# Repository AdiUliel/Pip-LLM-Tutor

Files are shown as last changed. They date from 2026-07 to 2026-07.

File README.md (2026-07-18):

# Pip — Personal Tutor for Kids | Project by: Adi Uliel, Lotan Dahan & Maor Amitay

## Details about the project

Pip is a robot that tutors children aged 7–11 in English or Math by voice
(powered by Google Gemini), with an animated face that keeps the child engaged.
A companion Flutter parent app is used for setup, homework materials and
progress reports.

Live web app: https://llm-tutor-d721e.web.app

**How to operate the device** (pairing, daily use, error messages, calibration):
see [Documentation/USAGE.md](Documentation/USAGE.md).

## Folder description :
* **ESP32**: source code for the esp side (firmware) — `homework_assistant/` is the main sketch, plus the modified TFT_eSPI library.
* **flutter_app**: Dart code for our Flutter parent app (Android / Web).
* **firebase**: Cloud side — Cloud Functions (session engine, Gemini grading, STT/TTS proxies), Firestore/Storage rules and indexes.
* **Documentation**: usage instructions (operating, error messages, calibration), hardware documentation + connection diagram, integration guide, cloud/LLM interface, dependencies, latency measurements, [performance evaluation](Documentation/PERFORMANCE_EVALUATION.md), [face state machine](Documentation/FACE_STATE_MACHINE.md) ([animated states](Documentation/pip_face_states.html)), [statistics catalog](Documentation/STATISTICS.md).
* **Unit Tests**: tests for individual hardware components (button, display+touch, microphone, speaker, firmware upload).
* **Parameters**: description of all hard-coded parameters and where to change them in the code.
* **Assets**: project poster + 3D-print (STL) files of Pip's enclosure.
* **pip_face**: standalone Arduino library for the animated on-device face (also mirrored into the main sketch).

## Hardware used in this project (+ quantities):
| Component | Qty | Notes |
|---|---|---|
| LCDWIKI 2.8" ESP32-S3 Display board (ES3C28P/ES3N28P) | 1 | Integrates the ILI9341 240×320 touch display (FT6336G), ES8311 audio codec + onboard microphone, FM8002E speaker amp, WS2812 RGB LED and a micro-SD slot |
| Speaker (wired to the board's amp output) | 1 | |
| Push-to-talk push button | 1 | Wired between IO2 and IO3 on the expansion header |
| micro-SD card | 1 | TTS audio cache |
| USB-C cable (power + flashing) | 1 | |
| 3D-printed enclosure (main body + rear cover) | 1 | STL files in [Assets/3D](Assets/3D) |

## ESP32 SDK version used in this project: 
* ESP32 by Espressif - version 2.0.17

## Arduino/ESP32 libraries used in this project:
* ArduinoJson by Benoit Blanchon - version 7.x
* TFT_eSPI by Bodmer - version 2.5.43 (modified for this board)
* pip_face (this repo) - animated on-device face

> Full dependency list (firmware, Flutter app, Cloud Functions) and the modified
> TFT_eSPI setup are documented in [Documentation/DEPENDENCIES.md](Documentation/DEPENDENCIES.md).

## Secrets setup (required to build the firmware):
Real credentials are **not** committed. Copy
[`ESP32/homework_assistant/secrets_template.h`](ESP32/homework_assistant/secrets_template.h)
to `ESP32/homework_assistant/secrets.h` and fill in your WiFi credentials and
Firebase project details (the real `secrets.h` is gitignored). The filled-in
file is available from the team on request.

## Connection diagram:
Most of the hardware is integrated on the LCDWIKI ESP32-S3 board — the only
external wiring is the push-to-talk button (IO2↔IO3) and the speaker.

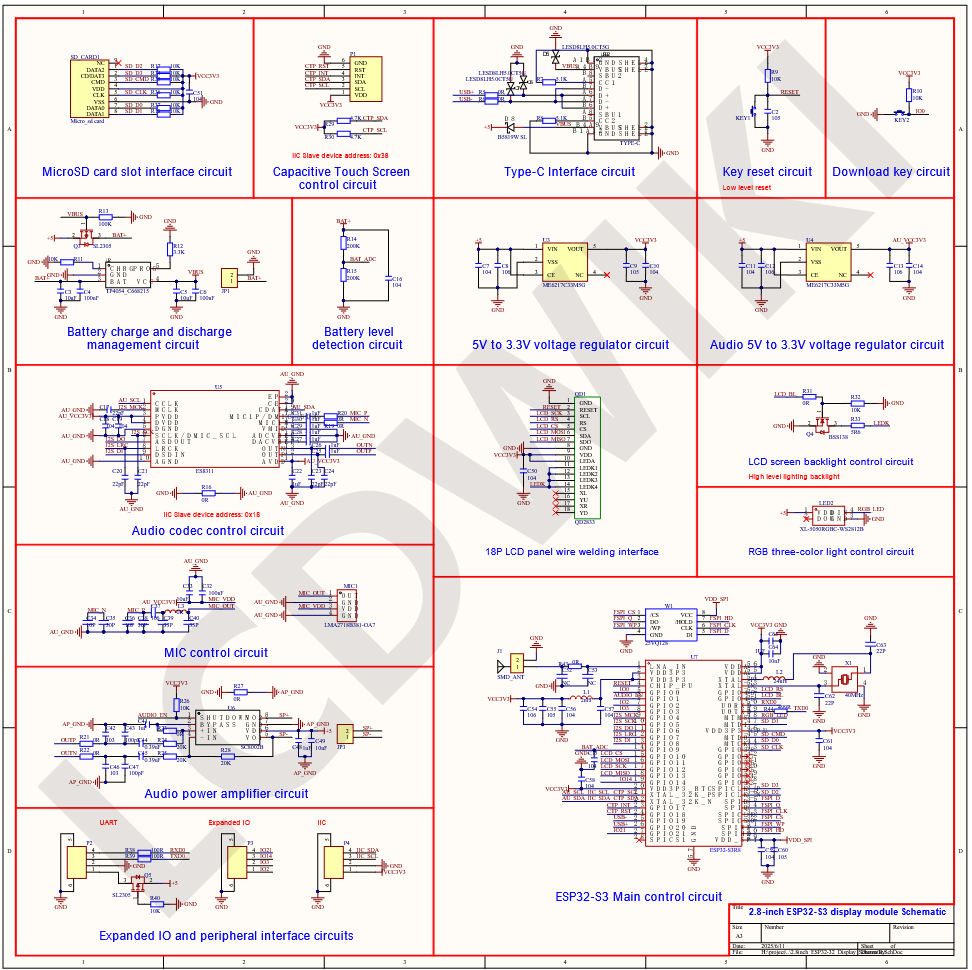
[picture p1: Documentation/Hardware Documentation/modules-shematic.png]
Modules schematic


* [Full ESP32-S3 Hardware Documentation (interactive)](Documentation/Hardware%20Documentation/index.html) ([PDF](Documentation/Hardware%20Documentation/Hardware%20Documentation.pdf))
* [System architecture (device ↔ Firebase ↔ Google APIs)](Documentation/ARCHITECTURE.md) — full data-flow diagram

## Project Poster:

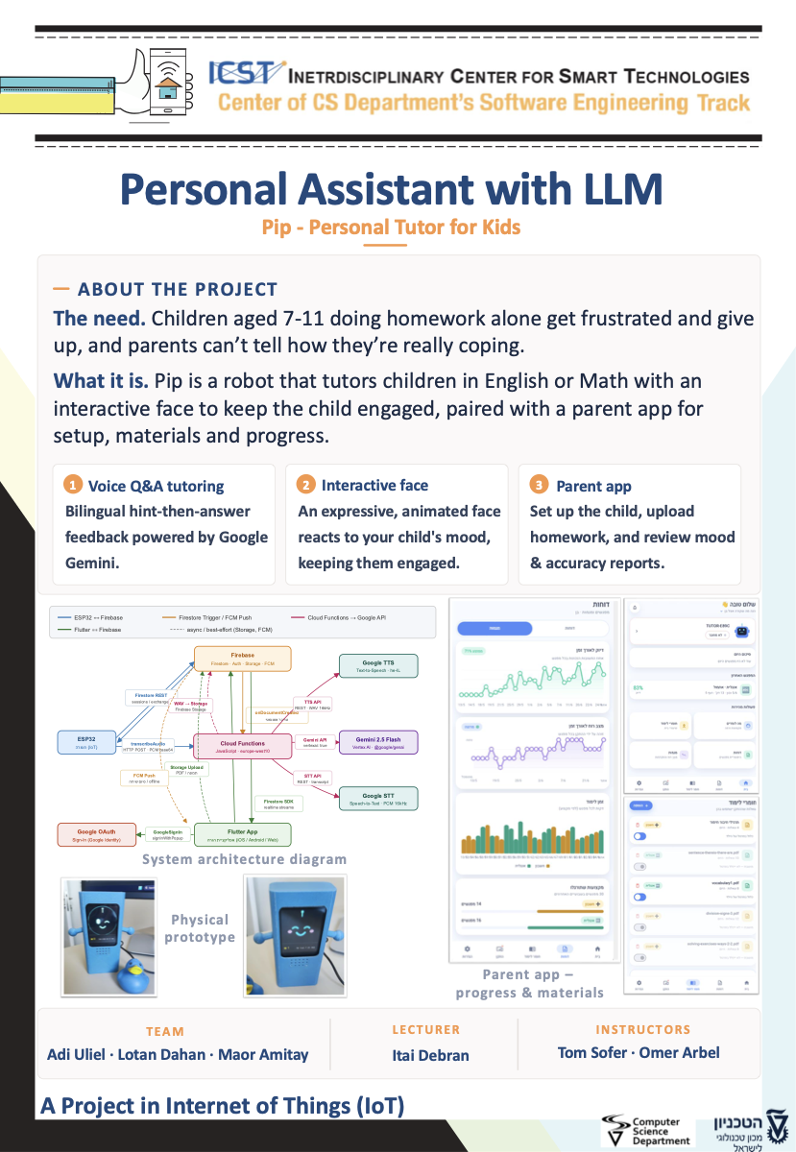
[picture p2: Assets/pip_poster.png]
Pip project poster


([PDF version](Assets/pip_poster.pdf))

This project is part of ICST - The Interdisciplinary Center for Smart Technologies, Taub Faculty of Computer Science, Technion
https://icst.cs.technion.ac.il/

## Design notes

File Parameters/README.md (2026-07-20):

# Parameters

All hard-coded (compile-time) parameters of the ESP32 firmware. Changing any of
them requires re-compiling and re-flashing the firmware.

They live in four files under `ESP32/homework_assistant/`:

| File | What it holds |
|---|---|
| `secrets.h` | Credentials + per-deployment config (copy from `secrets_template.h`) |
| `pins.h` | GPIO pin mapping + audio capture config for the LCDWIKI ESP32-S3 board |
| `homework_assistant.ino` (top of file) | Feature flags, bench-testing/demo switches, timing |
| `es8311.h` | Audio codec (volume / gain) registers |

`ESP32/parameters.h` is a fully-annotated reference copy of the board pin table.

---

## 1. Credentials & deployment config — `secrets.h`

> Gitignored. Copy `secrets_template.h` → `secrets.h` and fill in.

| Parameter | Default | Description |
|---|---|---|
| `WIFI_SSID` / `WIFI_PASSWORD` | — | WiFi network the device connects to |
| `FIREBASE_WEB_API_KEY` | — | Firebase Console → Project Settings → Web API Key |
| `FIREBASE_PROJECT_ID` | — | Firebase project id (from `.firebaserc`) |
| `CLOUD_FUNCTIONS_REGION` | `"europe-west10"` | Region the Cloud Functions are deployed to |
| `STT_LANGUAGE_CODE` | `"he-IL"` | BCP-47 language for Speech-to-Text (`"en-US"`, `"ar-IL"`, …) |
| `SESSION_SUBJECT` | `"math"` | Subject a session starts with: `"math"` or `"english"` |
| `CHILD_ID` | `""` | Fallback child profile id if no child has this device's UID; `""` = generic session |
| `NTP_SERVER` | `"pool.ntp.org"` | Time server (needed for Firestore timestamps + heartbeat freshness) |

## 2. Feature flags — `homework_assistant.ino`

| Parameter | Default | Description |
|---|---|---|
| `USE_PROCESS_TURN` | `1` | `1` = one synchronous `processTurn` cloud call per turn (grade+LLM+TTS inline). `0` = legacy post-and-poll path (A/B fallback) |
| `USE_PROCESS_TURN_AUDIO` | `1` | `1` = upload raw PCM to `processTurn`; server runs STT (one round-trip, −33% bytes). `0` = transcribe on-device first. Requires `USE_PROCESS_TURN` |
| `BOREDOM_NUDGE_SECONDS` | `40` | Seconds of no interaction (screen on, waiting for an answer) before Pip shows a brief PLAYFUL wink to re-engage the child; `0` disables. Visual only, once per idle stretch |
| `HEARTBEAT_MS` | `10000` | Device→app heartbeat interval (ms); the app's online timeout is 30 s |
| `MIC_TARGET_PEAK` | `22000` | Auto-gain target peak for mic capture (~−3.4 dBFS) |
| `MIC_MAX_GAIN` | `12.0f` | Auto-gain cap (~+21.6 dB) |

## 3. Pins & audio capture — `pins.h`

Board: **LCDWIKI 2.8" ESP32-S3 Display (ES3C28P / ES3N28P)** — display, touch,
codec, mic, amp and SD are all onboard; only the speaker and the push-to-talk
button are external.

| Parameter | Default | Description |
|---|---|---|
| `PIN_AUDIO_EN` | `1` | FM8002E speaker-amp enable (LOW = on) |
| `PIN_I2S_MCLK` / `BCLK` / `LRCK` | `4` / `5` / `7` | I2S clocks to the ES8311 codec |
| `PIN_I2S_DOUT` / `PIN_I2S_DIN` | `8` / `6` | I2S data: ESP32→speaker / mic→ESP32 |
| `PIN_I2C_SDA` / `PIN_I2C_SCL` | `16` / `15` | I2C bus (ES8311 codec + FT6336G touch, shared) |
| `ES8311_I2C_ADDR` | `0x18` | Codec I2C address |
| `PIN_BTN` / `PIN_BTN_GND` | `3` / `2` | Push-to-talk button between IO2 (driven LOW as GND) and IO3 (`INPUT_PULLUP`, active LOW) |
| `PIN_RGB_LED` | `42` | Onboard WS2812 status LED |
| `PIN_LCD_BL` | `45` | LCD backlight enable (HIGH = on); other LCD pins are fixed in the TFT_eSPI `User_Setup` |
| `I2S_PORT` | `I2S_NUM_0` | I2S peripheral used |
| `SAMPLE_RATE` | `16000` | Capture sample rate (Hz) — Google STT requirement |
| `SAMPLE_BITS` | `16` | Bits per sample |
| `MAX_RECORD_MS` | `7000` | Max push-to-talk recording length (ms); sizes the PSRAM record buffer (448 KB) |

SD-card (SDIO) pins for the TTS cache are in `tts_cache.h` / `parameters.h`
(`SD_CLK 38`, `SD_CMD 40`, `SD_DATA0–3 39/41/48/47`).

## 4. Audio codec — `es8311.h`

| Parameter | Default | Description |
|---|---|---|
| DAC volume register (`0x32`) | `0xC5` | Normal speaker loudness (~+3 dB; `0xBF` = 0 dB unity). Higher hex = louder |

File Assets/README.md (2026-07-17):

# Assets

Project media and 3D-printing files.

| File | Description |
|---|---|
| `pip_poster.pdf` | Project poster (original, print quality) |
| `pip_poster.png` | Poster rendered as an image (embedded in the root README) |
| `3D/pip_main_body.stl` | 3D-printed enclosure — main body (holds the LCDWIKI ESP32-S3 board, speaker and button) |
| `3D/pip_rear_cover.stl` | 3D-printed enclosure — rear cover |

## 3D printing notes

The enclosure was printed in PLA with standard settings (0.2 mm layer height, no
supports needed for the rear cover). The main body is sized for the LCDWIKI 2.8"
ESP32-S3 display board with the push-to-talk button wired to the IO2/IO3
expansion header.

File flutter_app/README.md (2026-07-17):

# Pip — Parent App

Flutter + Firebase **parent companion** for Pip, the ESP32-based voice tutor for
kids (ages 7–11). This app does **no tutoring** — that lives on the physical
device. The app lets a parent pair the device, configure the child, upload
homework materials, view reports + mood/accuracy trends, and monitor the device.

Hosted URL: https://llm-tutor-d721e.web.app

---

## Quick start

```bash
flutter pub get
flutter run        # local dev
flutter build web --release && firebase deploy --only hosting   # publish
```

The app talks to the real Firebase project (`llm-tutor-d721e`). Sign-in supports
**Email/Password** and **Google Sign-In** (popup on web, native picker on
Android); parent + child + material + session data live in Firestore; uploads go
to Storage.

Android APK build (JDK 17 required):

```bash
JAVA_HOME=/opt/homebrew/opt/openjdk@17/libexec/openjdk.jdk/Contents/Home \
flutter build apk --release
```

## Reconfigure the Firebase project

If you need to point the app at a different Firebase project:

1. Install the Firebase CLI and the FlutterFire CLI:
   ```bash
   curl -sL https://firebase.tools | bash
   dart pub global activate flutterfire_cli
   ```
2. From this directory, run `flutterfire configure` and pick the project; this
   regenerates `lib/firebase_options.dart`.

---

## Architecture

```
lib/
  main.dart            Firebase init + MultiProvider + provider wiring + runApp
  app.dart             MaterialApp · RTL (Hebrew) locale · auth-gate routing
  theme.dart           Design tokens
  constants.dart       Every tunable (no magic numbers) + Hebrew labels + enums
  firebase_options.dart  Generated by `flutterfire configure`
  models/              ParentUser · Child · Session · QuestionLog · MaterialDoc · DeviceState
  providers/           AuthProvider · ChildProvider · ConfigProvider · DeviceProvider · StatsProvider
  services/            FirebaseService + DeviceSyncService (abstract interfaces + real
                       implementations) · FcmService (push notifications)
  screens/             login · onboarding intro · setup wizard · shell (bottom-nav) ·
                       dashboard · child config · material upload/detail ·
                       reports hub/reports · session detail · trends ·
                       device monitor · settings · admin view
  widgets/             PairingSheet (device pairing) · RobotFace · charts/cards ·
                       OfflineBanner · wizard/stepper components
  utils/               offline_queue · validators · notifications
```

**Strict rule (per course req):** screens never touch Firestore directly.
Screens → providers → services. Every external IO sits behind a service
interface (`FirebaseService`, `DeviceSyncService`).

---

## Firestore data model (shared with the ESP32 device)

```
parents/{parentId}                     # WRITTEN BY APP
  name, email, createdAt

children/{childId}                     # WRITTEN BY APP
  parentId, name, age,
  subjectsEnabled: ["math","english"],
  topicFocus, level,
  settings: { sessionMinutes, breakEveryMinutes, dailyLimitMinutes,
              breakEveryQuestions, breakAfterMinutes,      # break policy
              screenOffMinutes, deviceSleepMinutes },      # idle power policy
  deviceId,                            # pairing: set via PairingSheet; a Cloud
  createdAt                            # Function keeps it unique per device

materials/{materialId}                 # WRITTEN BY APP
  childId, subject, title,
  items: [ { question, answer } ],     # extracted/validated Q&A pairs
  fileUrl, status, uploadedAt

deviceState/{deviceId}                 # device writes; app reads
  online, lastHeartbeat,
  status: "idle"|"asking"|"listening"|"feedback"|"break"|"error",
  activeSubject, currentQuestion

sessions/{sessionId}                   # device writes; app reads
  childId, subject, startedAt, endedAt,
  questionsAsked, correctCount, wrongCount, accuracy,
  starsEarned, longestStreak, moodSummary
  questions/ (subcollection)
    { prompt, expectedAnswer, childAnswerTranscript,
      correct, mood, difficulty, askedAt }
```

Pairing: the device shows a `TUTOR-XXXXXX` code on screen; the parent enters it
in the PairingSheet, which links `children/{id}.deviceId` to the device's UID
("newest wins" — a Cloud Function unlinks any other child). The app derives
"online" from the device heartbeat (timeout in `constants.dart`).

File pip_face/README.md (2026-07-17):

# PipFace

Animated procedural face for the ESP32-S3 + ILI9341 tutor device. Twelve emotion states drawn with simple shapes — no SD card, no image assets, ~30 fps via a 240×240 off-screen sprite.

## Hardware

- **MCU:** ESP32-S3 with **PSRAM enabled** (the sprite buffer is ~115 KB).
- **Display:** 2.8" IPS ILI9341V, 240×320, RGB565, 4-wire SPI, portrait orientation (face renders on the top 240×240; bottom 240×80 is the optional status strip — long questions word-wrap to two right-aligned lines).

## Dependencies

- [`TFT_eSPI`](https://github.com/Bodmer/TFT_eSPI) (Arduino Library Manager).
- [`U8g2_for_TFT_eSPI`](https://github.com/Bodmer/U8g2_for_TFT_eSPI) (Arduino Library Manager) — brings u8g2's Unicode-capable fonts to TFT_eSPI. PipFace uses `u8g2_font_unifont_t_hebrew` for the bottom status strip so Hebrew prompts ("כמה זה 5 כפול 8?") render correctly. A small bidi-lite pass reorders the codepoints so the LTR-rendering engine produces a RTL-correct visual.

`TFT_eSPI/User_Setup.h` must match your wiring. **For this project's LCDWIKI
2.8" ESP32-S3 board, use the pre-patched TFT_eSPI shipped in this repo**
(`ESP32/modified libraries/TFT_eSPI/` — its `User_Setup.h` is already
configured; see `Documentation/INTEGRATION.md` for why a stock TFT_eSPI
crashes on this board). The board's pins for reference:

```c
#define ILI9341_DRIVER       // works for ILI9341 and ILI9341V (same init)
#define TFT_MISO 13
#define TFT_MOSI 11
#define TFT_SCLK 12
#define TFT_CS   10
#define TFT_DC   46
#define TFT_RST  -1          // tied to board reset — no dedicated GPIO
#define TFT_BL   45
#define USE_HSPI_PORT        // required on this board

// IPS panels (this one is IPS) often need color inversion. If the demo
// looks inverted (black appears white), uncomment the next line:
// #define TFT_INVERSION_ON
```

## Quick start

1. Copy this folder into your Arduino `libraries/` directory (so the path is `libraries/pip_face/PipFace.h`).
2. Open **File → Examples → PipFace → PipDemo** and flash it. The face should cycle through all 12 emotions every ~2.6 s.
3. In your main sketch, include `PipFace.h` and call:

```cpp
#include "PipFace.h"

void setup() {
  Pip::begin();              // spawns the render task; false = PSRAM disabled
}

void onDeviceStateUpdate(const char* status, int mood) {
  Pip::setDeviceStatus(status, mood);   // driven by Firebase
}

void loop() {
  pollFirebase();             // your code — can block as long as it needs
}
```

The face renders on its own low-priority **FreeRTOS task** spawned in `begin()`. The task ticks at ~30 fps independently of your `loop()`, so the face stays smooth even when your main code is blocked on HTTPS calls, STT, audio playback, or I2S recording. You don't need to call `tick()` — it's a no-op kept for backwards compatibility.

## Status → emotion mapping

`setDeviceStatus()` speaks the project's `deviceState.status` vocabulary. Mood (1–5) refines the `feedback` state; pass `-1` if unknown.

| `deviceState.status` | Mood | → Pip emotion |
|---|---|---|
| `idle` | * | IDLE |
| `asking` | * | SPEAKING |
| `listening` | * | LISTENING |
| `feedback` | `>= 4` | PROUD |
| `feedback` | `<= 2` | CONCERNED |
| `feedback` | `3` or `-1` (unknown) | ENCOURAGING |
| `break` | * | SLEEPY |
| `error` | * | OOPS |

Unknown status strings are silently ignored (current state preserved).

`THINKING`, `HAPPY`, `CELEBRATING`, and `PLAYFUL` are not reachable through `setDeviceStatus()`. Use `Pip::setEmotion("happy")` etc. when your tutoring logic has finer-grained signals.

## API

```cpp
namespace Pip {
  bool begin();                                          // init TFT + sprite
  void tick();                                           // call every loop()
  void setEmotion(const char* label);                    // direct 12-state setter
  void setDeviceStatus(const char* status, int mood);    // project-vocabulary setter
  void setStrip(const char* questionOrLabel, int stars); // bottom strip (re-renders on change only)
}
```

All setters are non-blocking and safe to call as often as you want — strip redraws only fire when the underlying text/stars actually change.

## Pre-flash sanity (optional)

If you have `arduino-cli` installed locally you can compile-check the demo without flashing:

```
arduino-cli compile --fqbn esp32:esp32:esp32s3 pip_face/examples/PipDemo
```

This catches header path / TFT_eSPI symbol issues before the board is involved.

## Files

```
pip_face/
├── PipFace.h                       — public API
├── PipFace.cpp                     — drawing + state machine
├── library.properties              — Arduino library manifest
└── examples/
    └── PipDemo/
        └── PipDemo.ino             — flashable demo, cycles all states
```

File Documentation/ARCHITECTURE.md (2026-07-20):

# System Architecture — Pip LLM Tutor

End-to-end data flow across the three parts of the system. The ESP32 device talks
only to Firebase (never directly to the AI APIs); the Cloud Functions call Google
Cloud AI services using the **project service account (ADC)** — there are no LLM
API keys stored anywhere.

```mermaid
flowchart TB
    subgraph Device["🧸 ESP32-S3 device"]
        ESP[Firmware<br/>mic · speaker · display · button]
    end

    subgraph Cloud["☁️ Firebase / Google Cloud"]
        CF[Cloud Functions<br/>processTurn · tutor engine<br/>extractQuestions · triggers]
        FS[(Firestore<br/>sessions · questions · children<br/>materials · deviceState · pairingCodes)]
        ST[(Storage<br/>homework files · TTS cache)]
        subgraph AI["Google Cloud AI APIs — via service account, no keys"]
            STT[Speech-to-Text]
            GEM[Gemini 2.5 Flash-Lite<br/>Vertex AI]
            TTS[Text-to-Speech he-IL]
        end
    end

    subgraph App["📱 Flutter parent app — Android / Web"]
        FL[Setup · materials · reports · device monitor]
    end

    ESP -- "raw PCM audio + sessionId (processTurn)" --> CF
    CF -- "result + inline TTS MP3" --> ESP
    ESP -- "deviceState heartbeat + anon auth (direct REST)" --> FS

    CF --> STT
    CF --> GEM
    CF --> TTS
    CF -- "session / questions / stats" --> FS
    CF -- "read materials · cache TTS" --> ST

    FL -- "read reports / device status" --> FS
    FL -- "write child · pairing" --> FS
    FL -- "upload homework" --> ST
    CF -. "FCM push (lesson start/end, offline)" .-> FL
```

## Legend

- **Device → Cloud Functions:** one `processTurn` HTTPS call per answer — uploads
  the raw PCM audio, receives the graded feedback + the spoken MP3 inline
  (see [PERFORMANCE_EVALUATION.md](PERFORMANCE_EVALUATION.md)).
- **Device → Firestore (direct):** the device also writes its `deviceState`
  heartbeat and creates sessions over the Firestore REST API (anonymous auth), so
  the app sees it live.
- **Cloud Functions → AI:** STT transcribes, Gemini (Vertex AI) grades + generates
  feedback/questions, TTS synthesizes speech — all with the project service
  account, **no API keys**.
- **App ↔ Firestore/Storage:** the parent app reads reports/device status and
  writes children, pairing and uploaded materials; homework files go to Storage.
- **FCM:** best-effort push notifications (lesson start/end, device offline).

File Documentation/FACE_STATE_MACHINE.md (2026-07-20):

# Pip — Face State Machine

_Behaviour reference for the animated face on the device screen · Pip LLM Tutor_

This document describes the state machine of **Pip's face** — the character shown
on the device's ILI9341 display. It reflects **what the firmware actually drives
today** (grounded in `ESP32/homework_assistant/homework_assistant.ino` and
`pip_face/PipFace.cpp`), not just the original design intent — see §5 for where
the two differ.

Pip is drawn in solid cyan on a black RGB565 panel; states are distinguished by
eye/mouth shape and motion, not colour. The render runs on its own ~30 fps
FreeRTOS task, so the face keeps animating even while the main loop is blocked on
WiFi, STT, or audio.

---

## 1. How the face is driven

The firmware sets the face two ways, both defined near the top of the `.ino`:

- **`faceStatus(status)`** → `Pip::setDeviceStatus()` — the functional loop
  states, also mirrored to `deviceState.status` in Firestore so the parent app's
  device monitor shows the same thing.
- **`faceEmotion(label)`** → `Pip::setEmotion()` — a direct emotion, used for the
  per-turn feedback face and a few boot/setup moments.

Per answer, the backend (`tutorEngine.js`) returns an `emotion`, which the device
maps to a face via `pipEmotionFor()` and shows with `faceEmotion()`.

---

## 2. The core session loop

One turn advances in one direction: **ask → listen → think → react**, repeat.

```
                 ┌─────────────────────────────────────────────┐
                 ▼                                             │
  IDLE ─► SPEAKING ─► LISTENING ─► THINKING ─► [react] ─► SPEAKING (next Q)
 (idle)  (asking)    (listening)  (thinking)     │
                                                 ├─ correct, single       → HAPPY
                                                 ├─ correct, streak ≥2     → PROUD
                                                 ├─ correct, streak ≥5     → CELEBRATING
                                                 ├─ wrong, 1st attempt     → ENCOURAGING (hint, retry)
                                                 └─ wrong, streak ≥2        → CONCERNED (easier next)
```

- **Correct answer** → `happy`; a solid streak (≥2) → `proud`; a rare long streak (≥5) → `celebrating` → next question.
- **Wrong answer** → `encouraging`, a hint, and the *same* question again; a second miss reveals the answer and moves on. A run of misses (streakWrong ≥2) → `concerned` and the engine drops the difficulty.
- Background **monitoring states** can interrupt at any time: SLEEPY for a break, OOPS for errors, and PLAYFUL as a brief re-engagement wink when the child goes quiet mid-question. Afterwards the device returns toward IDLE/LISTENING.

---

## 3. State reference — every face and what triggers it

This is the **complete list**: all 12 faces and exactly what makes each one
appear. **All 12 are reachable — there are no dead states.** The **Set via**
column says *how* the firmware picks the face (see §1):

- **deviceState** — chosen through the device status via `faceStatus(...)` (also
  mirrored to `deviceState.status` so the parent app shows the same thing).
- **emotion** — chosen directly via `faceEmotion(...)`.
- **both** — happens through either path depending on the moment.

| State (pip) | Trigger in firmware | Set via |
|---|---|---|
| **IDLE** | Nothing happening / end of another state (`faceStatus("idle")`) | deviceState |
| **SPEAKING** | Device is reading a question or feedback aloud (`"asking"`, `faceEmotion("speaking")`) | both |
| **LISTENING** | Waiting for / capturing the child's answer (`"listening"`) | both |
| **THINKING** | Boot, WiFi/connect, identify flow, and while a turn is being processed (`faceEmotion("thinking")`) | emotion |
| **HAPPY** | A single correct answer (backend `emotion:"happy"`; also `neutral`) | emotion |
| **PROUD** | Correct answer on a solid streak — `streakCorrect ≥ 2` (backend `emotion:"proud"`) | emotion |
| **CELEBRATING** | Correct answer on a rare long streak — `streakCorrect ≥ 5` (backend `emotion:"celebrating"`); also the "connected ✓" moment right after successful pairing | emotion |
| **ENCOURAGING** | First wrong attempt / hint, and the default feedback face | emotion |
| **CONCERNED** | Child is struggling — `streakWrong ≥ 2` (backend `emotion:"concerned"`) | emotion |
| **PLAYFUL** | Boredom nudge — no interaction for `BOREDOM_NUDGE_SECONDS` (40 s) while waiting for an answer with the screen on; a brief wink, then back to LISTENING | emotion |
| **SLEEPY** | Break time (`faceStatus("break")`); also the calm "waiting to be set up" face on an **unpaired** device | both |
| **OOPS** | Technical error — WiFi lost, Firebase auth failed, or a network hiccup mid-answer (`faceStatus("error")` at boot; `faceEmotion("oops")` on a failed turn upload) | both |

Animation/duration details (blink cadence, cross-fades, per-state motion) are as
in the original design doc; the firmware keeps the ~30 fps partial-update render
and slow, non-strobing motion for child safety.

---

## 4. Emotion mapping (backend → face)

This table is **narrower than §3**: it only covers the **single feedback face
shown after each answer**. The cloud returns an `emotion` word for the turn, and
`pipEmotionFor()` in the firmware translates it to one of the five feedback
faces:

| Backend `emotion` | Face shown |
|---|---|
| `celebrating` | CELEBRATING |
| `proud` | PROUD |
| `happy` | HAPPY |
| `neutral` | HAPPY |
| `encouraging` | ENCOURAGING |
| `concerned` | CONCERNED |
| *(anything else)* | ENCOURAGING (safe default) |

So §3 is the full picture (all 12 faces, all triggers); §4 zooms in on just the
after-answer feedback face and how the cloud's word maps to it. The other
faces — IDLE, SPEAKING, LISTENING, THINKING, SLEEPY, OOPS — are set directly by
the firmware (the `faceStatus`/`faceEmotion` calls in §3), **not** through this
mapping.

---

## 5. Notes on the implementation

All 12 designed face states are reachable. The two celebration/engagement
states work as follows:

- **PROUD** — the backend emits `emotion:"proud"` for a solid correct streak
  (`streakCorrect ≥ 2`), and `pipEmotionFor()` maps it to the PROUD face.
  CELEBRATING is reserved for a rare long streak (`≥ 5`), keeping it special.
- **PLAYFUL** — the firmware shows a brief PLAYFUL wink when the child goes quiet
  mid-question (no interaction for `BOREDOM_NUDGE_SECONDS`, default 40 s, while
  the screen is on), then returns to LISTENING. It is visual only — Pip never
  interrupts with sound — and fires at most once per idle stretch.

A few states do double duty by design:

- **SLEEPY** — the scheduled break *and* the "waiting to be paired" screen on an
  unpaired device.
- **CELEBRATING** — an in-lesson milestone *and* the "connected ✓" moment right
  after successful pairing.
- **THINKING** — while checking an answer, and also at boot and during
  WiFi/connect.

---

_For a print-ready copy, open this file in any Markdown viewer and export to PDF._

_See also [`pip_face_states.html`](pip_face_states.html) — a standalone interactive
page showing all 12 face states animated as vectors._

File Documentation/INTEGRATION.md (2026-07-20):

# Edge-to-Edge Integration

How the three parts — **ESP32 device**, **Cloud Functions / Firebase**, and the
**Flutter parent app** — are wired together for an end-to-end test, and what you
have to do to deploy and run it.

## The connected flow

```text
   ESP32 device                Firebase / Cloud Functions              Flutter app
 ┌───────────────┐            (region: europe-west10)               ┌───────────────┐
 │ button + mic  │                                                  │ device monitor │
 │ ES8311 codec  │   1. create session {childId, deviceId,          │ reports/trends │
 │ ILI9341 +     │      subject, startedAt} ───────────────▶        │ child config   │
 │ pip_face      │      onSessionCreated seeds the first            └───────┬───────┘
 └──────┬────────┘      question + its TTS audio                            │
        │                                                                   │
        │ 2. speak question, record answer (push-to-talk)                   │
        │ 3. POST raw PCM ──▶ processTurn:                                  │
        │       STT → grade → Gemini (gated) → TTS,                         │
        │       writes sessions/questions/exchanges docs ───────────────────┤
        │ 4. response: feedback + emotion + next question                   │ watches
        │       in headers, MP3 audio in the body                           │ sessions,
        │ 5. show emotion, speak audio, loop to 2                           │ questions,
        │                                                                   │ deviceState
        └── deviceState/{deviceId}: status + heartbeat every 10 s ──────────┘
```

The device, functions, and app all read/write the **same Firestore documents** —
that shared schema is what connects them. See `LLM_INTERFACE.md` for field-level
detail. (`answerQuestion`, a Firestore-trigger route, stays deployed as the
app-initiated / fallback path.)

## How each part is wired

**Cloud Functions (`firebase/functions/`)**
- `setGlobalOptions({ region: "europe-west10" })` so *all* functions run in one
  region. The functions must use the Firebase Functions v2 API for this global
  option to apply.
- Gemini runs through the Vertex **`global`** endpoint; the tutor feedback uses
  `gemini-2.5-flash-lite` and material extraction uses `gemini-2.5-flash`.
- **TTS audio** is synthesized for every spoken reply; on the trigger path the
  audio is uploaded *before* `status:"done"`, so a polling device never sees a
  done doc without an `audioUrl`.
- The `onSessionCreated` trigger seeds the first question and its audio when the
  device creates a session with `awaitingFirstQuestion:true`.

**ESP32 firmware (`ESP32/homework_assistant/`)**
- Drives the full adaptive tutor loop (speak question → listen → grade → speak
  feedback + next question → repeat).
- Session creation sends the full **rules-required** document (`childId,
  deviceId, subject, startedAt`) so the Firestore security rules accept it.
- **Child auto-detect:** queries `children` where `deviceId ==` this device's
  Firebase UID; falls back to `CHILD_ID` in `secrets.h` (the Firestore child
  document ID, not the device UID); else runs generic.
- **NTP clock** + ISO-8601 timestamps so Firestore timestamps and the app's
  online/heartbeat check work.
- Writes `deviceState/{deviceId}` on every state change and every 10 s so the
  app's device monitor shows the device live.
- **pip_face integrated:** shows the emotion returned by the backend, plus
  speaking/listening/thinking/break states, and the current question on the
  bottom strip.

**pip_face (`pip_face/`)**
- README wiring example matches *this* board (GPIO8 is the I2S speaker line,
  so the display uses different DC/RST pins). The configured `User_Setup.h`
  ships with the patched TFT_eSPI in `ESP32/modified libraries/TFT_eSPI/`.

**Rules**
- One `storage.rules` ruleset covers both the device's `tts/` public read and
  the app's `materials/` authenticated read/write; the `firebase/` and
  `flutter_app/` copies are identical.

## Deploy

```bash
# 1. Backend (functions + Firestore + Storage rules), from firebase/
cd firebase
npm install --prefix functions
firebase login
firebase use <project-id>
firebase deploy --only functions,firestore:rules,storage

# 2. Flutter app
cd ../flutter_app
flutter pub get
flutter run            # or: flutter build apk / flutter build web
```

> If `firebase deploy` rejects `europe-west10` for the Firestore-trigger
> functions, verify that the functions use the v2 API and that the selected
> region supports the required triggers and matches the Firestore location. If
> another supported region is used, update the backend region configuration,
> `CLOUD_FUNCTIONS_REGION` in `ESP32/homework_assistant/secrets.h`, and
> `AppConstants.functionsRegion` to match. `FUNCTIONS_REGION` only has an effect
> if the backend code reads that environment variable.

Also enable in the Google Cloud console: **Vertex AI**, **Cloud
Text-to-Speech**, **Cloud Speech-to-Text**, and **Firebase Storage**. Enable
**Anonymous Authentication** in Firebase Authentication, and make sure billing
and the runtime service-account permissions required by these services are in
place.

## Flash the device

1. Install Arduino libraries: **ArduinoJson** (v7).
2. Install **pip_face** as a library: copy the `pip_face/` folder into your
   Arduino `libraries/` directory.
3. **TFT_eSPI for this board — use the patched copy in this repo, NOT a stock
   install.** The stock TFT_eSPI ESP32-S3 SPI processor file crashes at
   `init()` on this board (`StoreProhibited`, write to `0x10`). This repo ships
   LCDWIKI's working, pre-patched TFT_eSPI 2.5.43 — processor file, ILI9341
   init, and a `User_Setup.h` (with `USE_HSPI_PORT`) already configured for
   this board:
   - Replace `Arduino/libraries/TFT_eSPI` with this repo's
     `ESP32/modified libraries/TFT_eSPI/`.
4. Fill in `ESP32/homework_assistant/secrets.h` (WiFi, project, optional
   `CHILD_ID`, `SESSION_SUBJECT`).
5. Board settings: ESP32S3 Dev Module, **PSRAM: OPI PSRAM**, Flash 16 MB,
   Partition "Huge APP".
6. Flash `homework_assistant.ino`.
7. Button line: `pins.h` uses IO3 (with IO2 as GND); if a unit's IO3 expansion
   line is flaky, switch `PIN_BTN` to GPIO0 (the onboard BOOT button).

## Test checklist (edge-to-edge)

1. In the app, create a child and set its **deviceId** to the value the device
   prints at boot (`Signed in anonymously. UID: …`). If auto-detection is not
   used, set `CHILD_ID` to the Firestore child document ID — **not** to the
   device UID. Leave `CHILD_ID` blank only when intentionally running in generic
   mode.
2. Power the device → it should print "first question ready", speak it, and show
   the listening face.
3. App → Device monitor shows the device **online** with the current question.
4. Hold the button, answer out loud, release → device shows thinking, then the
   emotion, and speaks the feedback + next question.
5. App → Reports / Session detail shows the question log filling in.

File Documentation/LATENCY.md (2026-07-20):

# Latency — the turn round-trip

How long it takes from *the child stops speaking* to *the robot starts speaking
the feedback*, and what the design does to keep that short. Setup: ESP32-S3 on
home Wi-Fi, a ~2–3 s spoken answer, Cloud Functions in `europe-west10`
(Berlin), device used from Israel. Full measured data and methodology:
[PERFORMANCE_EVALUATION.md](PERFORMANCE_EVALUATION.md).

## The turn — one synchronous call

The whole turn is a single HTTPS request. The device uploads the recorded
answer as raw PCM to `processTurn`, which runs every stage server-side and
returns everything in one response:

```text
device ──POST raw PCM (?fmt=pcm16)──▶ processTurn (warm instance)
                                        │ Speech-to-Text
                                        │ grade (deterministic)
                                        │ Gemini — only when feedback needs it
                                        │ Text-to-Speech
                                        │ write session/question/exchange docs
device ◀── feedback/emotion/next question in headers + MP3 in the body
```

The function still writes the same Firestore documents, so the parent app
follows the lesson live; the device itself never polls and never downloads
audio separately — the MP3 is decoded as the response streams in.

## What keeps it fast

- **One network hop per turn** — STT, grading, LLM and TTS run inside a single
  call; there is no device Firestore write, no trigger propagation, no poll
  loop, and no separate audio download.
- **Raw PCM upload** — no base64 (−33% bytes on the slow uplink).
- **Warm instances** (`minInstances: 1`) and the REST Firestore transport — no
  cold-start spike on the first answer.
- **The LLM is gated** — simple correct answers use deterministic feedback and
  skip Gemini entirely.
- **Gemini `gemini-2.5-flash-lite`, "thinking" disabled** — the reply is a
  short fixed-JSON (`maxOutputTokens: 180`), so the low-latency model variant
  is sufficient.
- **STT `command_and_search` model + phrase hints** — the short-utterance model
  fits one-word answers and names, and `speechContexts` bias recognition toward
  the current expected answer (boost 20).
- **Keep-alive TLS on the device** — connections are reused, avoiding a
  ~0.3–0.6 s handshake per request.
- **Feedback and next-question generation run in parallel** server-side, and
  question generation is fully local (no LLM call).

## Measured results

End-to-end turn (`RECORD → FIRST SOUND`, button release to first audio sample):

| Design | Correct turn | Wrong turn (Gemini) | Network hops |
|---|---|---|---|
| Polling design (write → trigger → poll → download) | 14.8 s | 17–19 s | 5 |
| **Single-call design (current)** | **4.0–4.3 s** | **5.8 s** | 1 |

Per-stage server breakdown, from the `[lat]` log inside `processTurn`
(15 turns, home Wi-Fi, warm):

| Stage | Measured |
|---|---|
| STT (upload + recognition, with hints) | 0.45–0.72 s |
| Grade + TTS, LLM skipped (correct answer) | 0.4–1.7 s |
| Grade + Gemini + TTS (wrong answer) | 2.0–2.9 s |
| PCM upload size per answer | 40–82 KB |

The dominant remaining cost on a wrong answer is the Gemini call; on top of
every stage sits the Israel↔EU round trip to `europe-west10`. The LLM row was
measured with `gemini-2.5-flash`; the deployed model is `gemini-2.5-flash-lite`
(set via the `GEMINI_MODEL` environment variable).

## How it is measured

- **Device:** each stage is wrapped in `millis()` deltas and printed as
  `[lat] …` serial lines; the key metric is `RECORD → FIRST SOUND`.
- **Server:** `processTurn` logs `[lat] session=… stt=…ms turn=…ms pcm=…B
  llm=…` per turn to Cloud Logging, separating upload+STT from
  grade+Gemini+TTS.

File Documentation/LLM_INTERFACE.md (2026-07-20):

# LLM Interface — Pip LLM Tutor

The LLM integration layer of the tutor. It is implemented in Firebase Cloud
Functions so the ESP32 device does **not** hold an API key and does **not**
call Gemini directly.

## High-level flow

Primary path — one synchronous HTTPS call per turn (`processTurn`):

```text
Child speaks (push-to-talk)
  ↓
Device uploads the raw PCM audio to processTurn
  ↓
processTurn: Speech-to-Text → grade the answer → Gemini feedback (only when
needed) → generate next question → Text-to-Speech
  ↓
Device receives feedback + next question in the response headers and the MP3
audio in the response body, and speaks/displays it
```

The function still writes the same `sessions` / `questions` / `exchanges`
documents, so the parent app follows the lesson live from Firestore. A
Firestore-trigger path (`answerQuestion`, described below) remains deployed as
the app-initiated / fallback route.

## Main Firestore collections

```text
children/{childId}
  name
  age
  gender
  subjectsEnabled
  topicFocus
  level
  deviceId

sessions/{sessionId}
  childId
  deviceId
  subject: "math" | "english"
  status: "starting" | "active" | "break" | "ended"
  currentDifficulty
  currentQuestion
  currentExpectedAnswer
  currentTopic
  currentAnswerVariants
  lastFeedback
  lastEmotion
  shouldTakeBreak
  questionsAsked
  correctCount
  wrongCount
  starsEarned
  consecutiveCorrect
  consecutiveWrong

sessions/{sessionId}/exchanges/{exchangeId}
  type: "learning_turn"
  status: "pending" | "processing" | "done" | "error"
  childAnswer
  spokenFeedback
  emotion
  nextQuestion
  expectedAnswer
  isCorrect
  shouldTakeBreak

sessions/{sessionId}/questions/{questionId}
  prompt
  expectedAnswer
  childAnswerTranscript
  correct
  mood
  difficulty
  feedback
  emotion
```

## ESP32 / device write format

When the child answers the current question, write a new document:

```json
{
  "type": "learning_turn",
  "status": "pending",
  "childAnswer": "תשע",
  "askedAt": "server timestamp"
}
```

Path:

```text
sessions/{sessionId}/exchanges/{exchangeId}
```

The Cloud Function will update the same document with:

```json
{
  "status": "done",
  "isCorrect": true,
  "spokenFeedback": "נכון מאוד! כל הכבוד!",
  "emotion": "happy",
  "nextQuestion": "כמה זה 6 ועוד 3?",
  "expectedAnswer": "9",
  "shouldTakeBreak": false,
  "audioUrl": "https://storage.googleapis.com/<bucket>/tts/<exchangeId>.wav"
}
```

`audioUrl` is a 16 kHz LINEAR16 WAV containing **spokenFeedback + nextQuestion**
spoken together, synthesized by the function *before* it flips `status` to
`done` (so the polling device never reads a done doc with an empty URL).

The device should then:

1. Display the pip_face emotion from `emotion`.
2. Play `audioUrl` (feedback then the next question).
3. Treat `nextQuestion` as the new current question.
4. Wait for the next child answer.

### First question

The device does **not** speak the very first question from an exchange — it is
seeded on the session itself by the `onSessionCreated` trigger:

```text
sessions/{sessionId}
  status: "active"
  currentQuestion: "כמה זה 4 ועוד 5?"
  currentExpectedAnswer: "9"
  currentQuestionAudioUrl: "https://storage.googleapis.com/<bucket>/tts/<sessionId>_q0.wav"
```

### Live device status for the app

The device also writes `deviceState/{deviceId}` (deviceId == its anon UID) on
every state change and every ~10s as a heartbeat, so the Flutter device monitor
shows it live:

```text
deviceState/{deviceId}
  status: "idle" | "asking" | "listening" | "feedback" | "break" | "error"
  lastHeartbeat: <server/NTP timestamp>   // freshness drives "online"
  currentQuestion: string
  activeSubject: "math" | "english"
```

## Callable Functions for testing / Flutter

### `startLearningSession`

Input:

```json
{
  "childId": "CHILD_ID",
  "deviceId": "DEVICE_ID",
  "subject": "math"
}
```

Output:

```json
{
  "sessionId": "...",
  "currentQuestion": "כמה זה 4 ועוד 5?",
  "expectedAnswer": "9",
  "difficulty": 1
}
```

### `submitChildAnswer`

Input:

```json
{
  "sessionId": "SESSION_ID",
  "childAnswer": "תשע"
}
```

Output:

```json
{
  "exchangeId": "...",
  "status": "pending"
}
```

The Firestore trigger `answerQuestion` processes this pending exchange.

## Deploy

From the `firebase/` folder:

```bash
cd firebase/functions
npm install
cd ..
firebase deploy --only functions,firestore:rules
```

## Region

All Cloud Functions deploy to **europe-west10**, set once at the top of
`index.js`:

```js
const { setGlobalOptions } = require("firebase-functions/v2");
setGlobalOptions({ region: "europe-west10" });
```

This covers `answerQuestion`, `onSessionCreated`, `startLearningSession`,
`submitChildAnswer` and `transcribeAudio`. The ESP32 builds the STT URL from
`CLOUD_FUNCTIONS_REGION` in `secrets.h` (already `europe-west10`), and the
Flutter app uses `AppConstants.functionsRegion`.

## Gemini / Vertex AI notes

The code uses `@google/genai` with Vertex AI mode:

```js
new GoogleGenAI({
  vertexai: true,
  project: process.env.GCLOUD_PROJECT,
  location: process.env.GEMINI_LOCATION || "global"
});
```

The function uses the Cloud Function service account instead of a public API key.
Make sure Vertex AI / Gemini is enabled in the Firebase Google Cloud project.

We use the Vertex **`global`** endpoint for Gemini because model availability is
not uniform across regions (Berlin/europe-west10 does not serve every Gemini
model). The *functions* still run in europe-west10; only the model endpoint is
global. To pin a specific region instead, set `GEMINI_LOCATION`.

Models in use: the tutor feedback engine runs `gemini-2.5-flash-lite` (low
latency; the reply is a short fixed-JSON, so the lite model is sufficient), and
homework-material question extraction runs `gemini-2.5-flash` (multimodal PDF /
image analysis). Both are overridable via environment variables.

Optional environment variables:

```text
GEMINI_MODEL=gemini-2.5-flash-lite
GEMINI_LOCATION=global
FUNCTIONS_REGION=europe-west10
```

## Why the LLM is behind Cloud Functions

- Keeps API keys / service account credentials away from the device.
- Lets the app and device share the same tutor logic.
- Keeps session history and reports consistent.
- Allows fallback logic if Gemini fails.
- Central place for the child-safety filters and parent controls.

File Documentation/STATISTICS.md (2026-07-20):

# Statistics — Pip LLM Tutor

The statistics the system measures and can present: what the parent app shows,
the measured engineering numbers, the per-turn data captured for analytics, and
forward-looking additions. Everything is grounded in the actual data model
(field names below exist in Firestore).

---

## 1. Shown in the parent app

| Statistic | Where | Source |
|---|---|---|
| Lifetime totals: sessions, questions, stars | Trends → "סיכום כללי" card | `StatsProvider` aggregates over `sessions` |
| Active-days streak ("practised N days in a row") | Trends summary card | `StatsProvider.activeDayStreak` |
| Sessions this week + avg minutes/session | Trends summary card | `StatsProvider.sessionsThisWeek` / `avgSessionMinutes` |
| Minutes practised today | Dashboard "today ring" | `StatsProvider.minutesToday` |
| Per-session accuracy % and correct/total | Reports list | `session.correctCount / questionsAsked` |
| Stars earned + longest streak per session | Reports / session detail | `session.starsEarned`, `session.longestStreak` |
| Session duration + date + end reason | Reports list | `startedAt`, `endedAt`, `endReason` |
| Accuracy over time (chart) | Trends | `StatsProvider.accuracySeries` |
| Mood over time (chart) | Trends | `moodSummary` per session |
| Time spent per session, by subject (bar chart) | Trends | `session.durationMinutes` + `subject` |
| Subject split (math vs English) | Trends | `StatsProvider.sessionsBySubject` |
| Per-question log: prompt, transcript, correct/wrong, feedback | Session detail | `sessions/{id}/questions` subcollection |
| Device online/offline + current question live | Device monitor | `deviceState.lastHeartbeat` freshness |
| Average accuracy across sessions | Dashboard | `StatsProvider.averageAccuracy` |

## 2. Measured engineering statistics 

Real numbers, measured on hardware (see `latency-results.pdf` / `LATENCY.md`):

| Metric | Value |
|---|---|
| Turn latency (record-end → robot speaks), original | **14.8–19 s** |
| Turn latency, current single-call design | **4.0–5.8 s** |
| Improvement | **~3.5× faster** (10–13 s cut per turn) |
| Serial network hops per turn | **5 → 1** |
| Audio delivery: URL download → inline decode | **2.6–3.8 s → 2–4 ms** |
| Cold-start spike eliminated | was up to **+12 s** on the first answer |
| Gemini hint call (only on wrong answers) | adds **~1.5 s** |
| SD-cached prompt playback vs cloud synth | **tens of ms vs ~2–3 s** |
| Raw-PCM upload vs base64 | **−33% bytes** on the uplink |

Codebase (counted from the repo, 2026-07-17):

| Metric | Value |
|---|---|
| Total code | **~18,400 LOC**: firmware 3,671 · Cloud Functions 2,985 · Flutter app 10,496 · pip_face 733 · HW unit tests 512 |
| Deployed Cloud Functions | **12** (4 HTTP, 2 callable, 5 Firestore triggers, 1 scheduled) |
| Firestore collections | **8** (children, sessions, exchanges, questions, materials, parents, deviceState, pairingCodes) |
| Question bank | **105 English vocab words** across 12 topics + **20 grammar questions** + procedurally-generated math (4 operations × 10 difficulty levels) |
| pip_face emotions/states | **12** (idle, speaking, listening, thinking, happy, proud, celebrating, encouraging, concerned, playful, sleepy, oops) — see `FACE_STATE_MACHINE.md` |
| Pre-cached spoken phrases | **8** (SD cache, warmed at boot) |
| Languages | Hebrew UI + speech, English content; he-IL / en-US STT |

## 3. Per-turn data now captured 

Each answered question writes these fields (in `tutorEngine.js`); the data
accumulates from deploy onward and can be charted in the app with a query only —
no further backend work:

| Field (where) | Unlocks |
|---|---|
| `questions.topic` | **Accuracy by topic** ("strong in colors, weak in division") — the most actionable insight for a parent |
| `questions.difficulty` | **Accuracy by difficulty level** — shows the adaptive engine working on the 1–10 ladder |
| `questions.fromMaterial` | **Material vs generated**: share and accuracy on parent-uploaded homework |
| `questions.mood` + `questions.correct` | **Mood ↔ accuracy correlation** — the emotional-tutor premise, with data |
| `session.longestStreak` | **Longest correct streak** in the session — rendered in the session summary |
| `children.levelHistory[]` (`{subject, level, at}`) | **Level progression over time** — the clearest "is my child improving" curve |
| `exchange.llmUsed` | **LLM skip rate**: % of turns answered deterministically (the `needsLLM` gate) — quantifies the cost/latency win |
| `exchange.processingMs` + `session.processingMsTotal` | **Live turn-latency distribution / averages** in production, continuing the LATENCY.md story |
| `exchange.llmInputTokens`/`llmOutputTokens` + `session.llmInputTokensTotal`/`llmOutputTokensTotal` | **Gemini token usage & cost per lesson** — "a full lesson costs ~X agora" |
| `exchange.ttsChars` + `session.ttsCharsTotal` | **TTS characters synthesized** — the other half of the per-lesson cost model |
| `session.sttEmptyCount` | **STT-empty / reprompt rate** — real-world audio-robustness signal (how often no speech was recognised) |
| `material.itemsCount` + `material.extractionTruncated` | **Materials funnel** — questions extracted per uploaded file, and whether extraction was cut off |

**Device-side telemetry** — written to `deviceState/{uid}` on every state
transition (engineering/reliability data, not parent-facing):

| Field | Shows |
|---|---|
| `wifiRssi` | Wi-Fi signal strength (dBm) — coverage / connectivity quality |
| `freeHeap` | free heap bytes — memory-health watchdog |
| `uptimeSec` | seconds since boot — session stability |
| `bootCount` | cold boots + deep-sleep wakes (RTC-persisted) — activation count |
| `ttsCacheHits` / `ttsCacheMisses` | **TTS cache hit rate** — how often a spoken phrase was served instantly from SD vs synthesized in the cloud |

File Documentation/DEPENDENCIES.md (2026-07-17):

# Dependencies & Libraries

Full library/dependency list for the three parts of the project, plus the
board-specific modified TFT_eSPI setup. (The main `README.md` keeps only a short
summary and links here.) See also `INTEGRATION.md` for deploy/flash steps.

## ESP32 firmware (`ESP32/homework_assistant/`)

- **ArduinoJson** by Benoit Blanchon — v7.x (Firestore REST + STT JSON parsing)
- **TFT_eSPI** by Bodmer — v2.5.43, **modified for this board** (see below); drives the ILI9341 display via pip_face
- **pip_face** (this repo) — animated procedural face; depends on TFT_eSPI
- Built into the ESP32 core (no separate install): WiFi, WiFiClientSecure, HTTPClient, Wire (I2C → ES8311 codec), driver/i2s.h, time.h

Speech-to-Text and Text-to-Speech run server-side in Cloud Functions (Google
STT/TTS), so no on-device STT/TTS library is required.

### ⚠️ Modified TFT_eSPI (required for this board)

The stock TFT_eSPI from the Library Manager **crashes at `init()`** on the LCDWIKI
2.8" ESP32-S3 board (Guru Meditation: StoreProhibited, write to `0x10`) because of
its ESP32-S3 SPI processor file — independent of the pin config. **This repo ships
LCDWIKI's pre-patched TFT_eSPI 2.5.43** with the patched processor file, ILI9341
init, and a `User_Setup.h` (with `USE_HSPI_PORT` and the board pins) already
configured:

- Replace `Arduino/libraries/TFT_eSPI` with this repo's
  `ESP32/modified libraries/TFT_eSPI/`.

## Flutter app (`flutter_app/pubspec.yaml`)

- firebase_core ^4.10.0, firebase_auth ^6.5.2, cloud_firestore ^6.5.0, firebase_storage ^13.4.2, firebase_messaging ^16.3.0
- provider ^6.1.5, fl_chart ^1.2.0, file_picker ^11.0.2, http ^1.6.0, intl ^0.20.2
- shared_preferences ^2.5.5, google_fonts ^8.1.0, google_sign_in ^6.2.2, cupertino_icons ^1.0.8
- Dart SDK ^3.12.1

## Cloud Functions (`firebase/functions/package.json`)

- firebase-admin ^12, firebase-functions ^6, @google/genai ^1 (Vertex AI / Gemini)
- Node 22, deployed to region **europe-west10**

## Additional folders (not in the main README)

- **pip_face**: Arduino library for the animated on-device face (ESP32-S3 + ILI9341).
- **firebase**: Cloud Functions (tutor AI / LLM, STT & TTS proxies) + Firestore/Storage rules.
- **Documentation/INTEGRATION.md**: edge-to-edge wiring + deploy/flash steps.
- **Documentation/LLM_INTERFACE.md**: Firestore schema + LLM flow.

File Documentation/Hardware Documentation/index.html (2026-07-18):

# Hardware Documentation

2.8inch IPS ESP32-S3 (ES3C28P & ES3N28P) Display Module

## 1. Hardware Overview

The display module integrates a 2.8-inch IPS LCD, capacitive touch, ESP32-S3 main control, audio processing, and various peripheral interfaces. Below is the mapping of the physical components on the PCB.

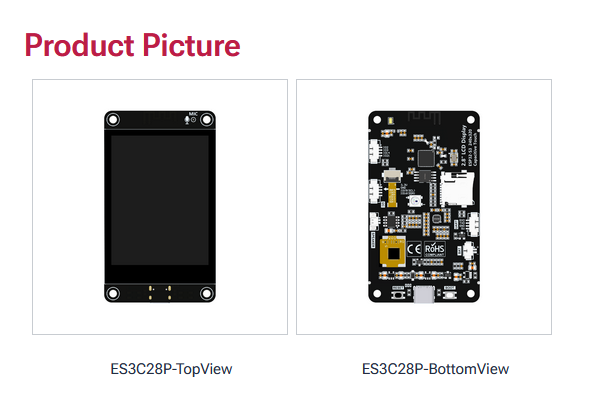
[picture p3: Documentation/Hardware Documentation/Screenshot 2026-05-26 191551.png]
Product Views (Front and Back)
 Module hardware resources (PCB Back View Components)

## 2. Display & Touch

### LCD Screen

The display is a 2.8-inch IPS screen driven by the ILI9341V IC with a resolution of 240x320. It connects to the ESP32-S3 using a 4-wire SPI communication interface. The ILI9341 uses 16 bits (RGB565) to control pixel display, supporting up to 65K colors.

Note: Refer to the ILI9341V datasheet for exact SPI timing diagrams and format structures.

### Capacitive Touch Screen

The touch interface uses the FT6336G control IC and communicates with the ESP32-S3 via the I2C bus (slave address: 0x38). It connects through a 0.5mm pitch FPC socket using four pins: CTP_RST, CTP_INT, CTP_SDA, and CTP_SCL.

Capacitive touch screen interface circuit

### LCD Backlight Control

Driven by a BSS138 N-channel MOSFET. A high level on the LCD_BL pin conducts the drain/source, illuminating the screen. It supports PWM signal input for brightness adjustment.

LCD backlight control circuit

### 18P LCD Panel Welding Interface

An 18-pin 0.8mm pitch interface that carries the SPI signals, screen voltage pins, backlight circuit pins, and touch signals.

18P LCD panel wire welding interface

## 3. Core Controller

The main control chip is the ESP32-S3R8, featuring an Xtensa dual-core 32-bit LX7 microprocessor (up to 240MHz). It includes 8MB of internal OPI PSRAM and connects to an external 16MB QSPI Flash.

- Supports 2.4GHz Wi-Fi and Bluetooth V5.0.
- Equipped with an onboard PCB antenna circuit.
- Utilizes a 40MHz passive crystal oscillator.
- Includes a CLC filtering circuit for analog power.

ESP32-S3 Main control circuit

## 4. Power Management

### Type-C Interface

Provides main power (5V), program downloading, and serial communication. Features a Schottky diode to prevent current reversal and static surge protection diodes.

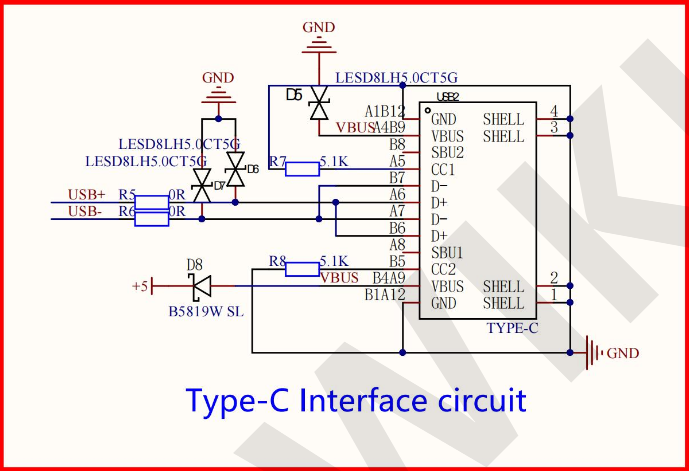
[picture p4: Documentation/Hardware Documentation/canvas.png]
Type-C Interface circuit


### 5V to 3.3V Voltage Regulators

Two separate ME6217C33M5G LDOs are used (max 800mA output) to isolate power paths: one exclusively for the audio circuits and one for the rest of the board.

5V to 3.3V voltage regulator circuit Audio 5V to 3.3V voltage regulator circuit

### Battery Management (Charge & Discharge)

Controlled by the TP4054 IC. A 2-pin 1.25mm pitch interface allows connecting a battery. The TP4054 limits charging current via a resistor (up to 500mA). A P-channel MOSFET (Q3) cuts off battery power when 5V Type-C power is present.

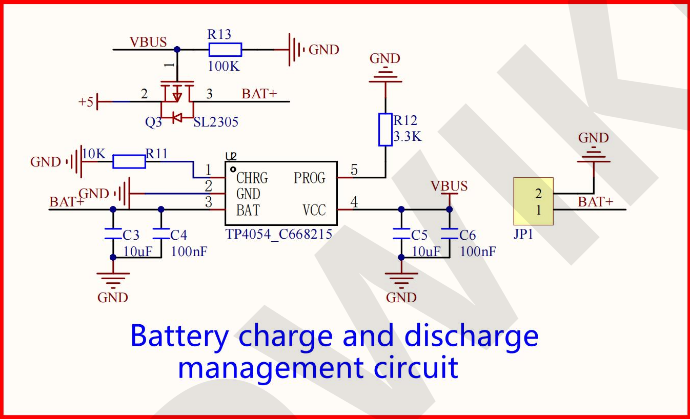
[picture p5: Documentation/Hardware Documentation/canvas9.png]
Battery charge and discharge management circuit


### Battery Level Detection

Since the battery saturation voltage (4.2V) exceeds the ESP32-S3's ADC maximum (3.3V), a voltage divider (two 200K resistors) scales the voltage down. The ADC reads this value, which must be multiplied by 2 in software to get the true battery voltage.

Battery level detection circuit

## 5. Audio Subsystem

### Audio Codec (ES8311)

The ES8311 IC handles decoding and encoding. It is configured via I2C (address 0x18) and transmits audio over the I2S bus. It processes incoming MIC signals (via ADC) and outputs audio signals to the amplifier (via DAC).

Audio codec control circuit

### Audio Power Amplifier (FM8002E)

The FM8002E receives differential signals (OUTP/OUTN) from the codec and amplifies them for the speaker. At 5V, it can drive 1.5W (8 ohm load) or 2W (4 ohm load). The volume is controlled by gain adjustment resistors.

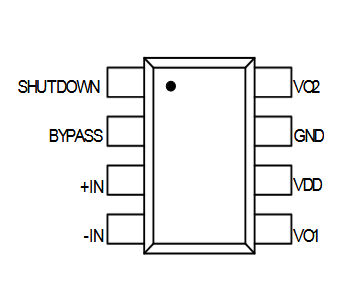
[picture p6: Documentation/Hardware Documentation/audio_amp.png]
Audio power amplifier circuit


### Microphone Control

A bottom-in MEMS silicon microphone is used for audio input. A CLC filtering circuit ensures clean signal transmission to the codec.

Hardware Identification Note: The PCB features a literal MIC marking alongside a small microphone icon/drawing indicating the exact location of the component.

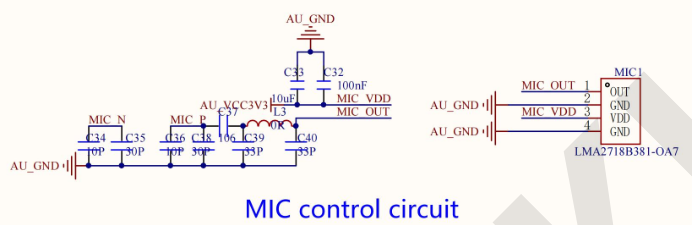
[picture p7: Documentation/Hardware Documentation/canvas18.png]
MIC control circuit


## 6. Expansion & Interfaces

### MicroSD Card Slot

Operates using the SDIO communication method rather than standard SPI, allowing for higher-speed storage access.

MicroSD card slot interface circuit

### Serial Module (UART)

A 4-pin 1.25mm interface exposing RXD0 and TXD0. Features impedance balancing resistors and an anti-reverse field-effect transistor on the 5V line.

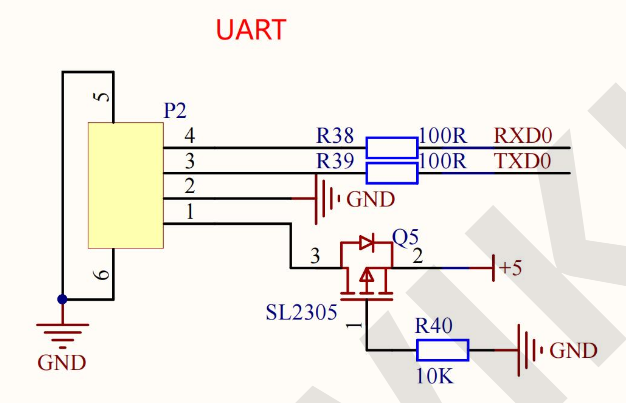
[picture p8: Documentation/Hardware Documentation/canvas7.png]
Interface circuit of serial module


### Expanded IO & I2C

Provides a 4-pin interface for general IO (IO21, IO14, IO3, IO2) which can double as an SPI bus, plus a dedicated 4-pin header for the I2C bus (IIC_SDA, IIC_SCL). The I2C pins cannot be used as standard GPIO.

Extended IO and peripheral interface circuits

## 7. Controls & Indicators

### Buttons

RESET Key (KEY1): Grounds the reset pin of the ESP32-S3. An RC circuit provides delay to ensure stable resets.

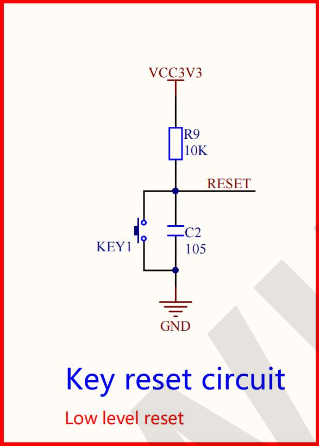
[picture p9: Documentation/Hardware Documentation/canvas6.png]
Key reset circuit


BOOT Key / Download Key (KEY2): Grounds IO0. Holding this while resetting places the ESP32-S3 into download mode. It can otherwise act as a general-purpose button.

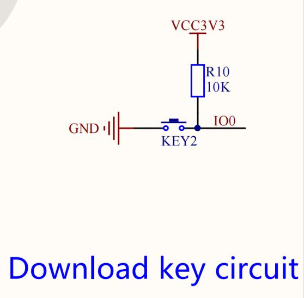
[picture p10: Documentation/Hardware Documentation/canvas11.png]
Download key circuit


### RGB LED (WS2812B)

A built-in tri-color RGB LED utilizing an internal IC. Powered by 5V, it requires only a single IO pin to generate different color output based on timing waveforms.

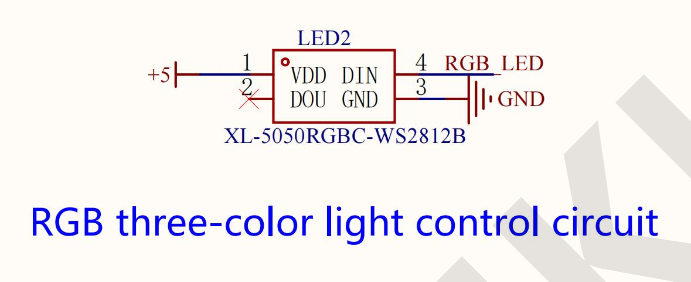
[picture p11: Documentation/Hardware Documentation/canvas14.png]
RGB three-color light control circuit


## 8. Push-to-Talk Button

Sections 1–7 above describe the stock module. This section documents wiring added for the Pip LLM Tutor project: an external momentary button the child holds while answering. It uses two pins of the P3 expanded IO header described in section 6, and needs no external components.

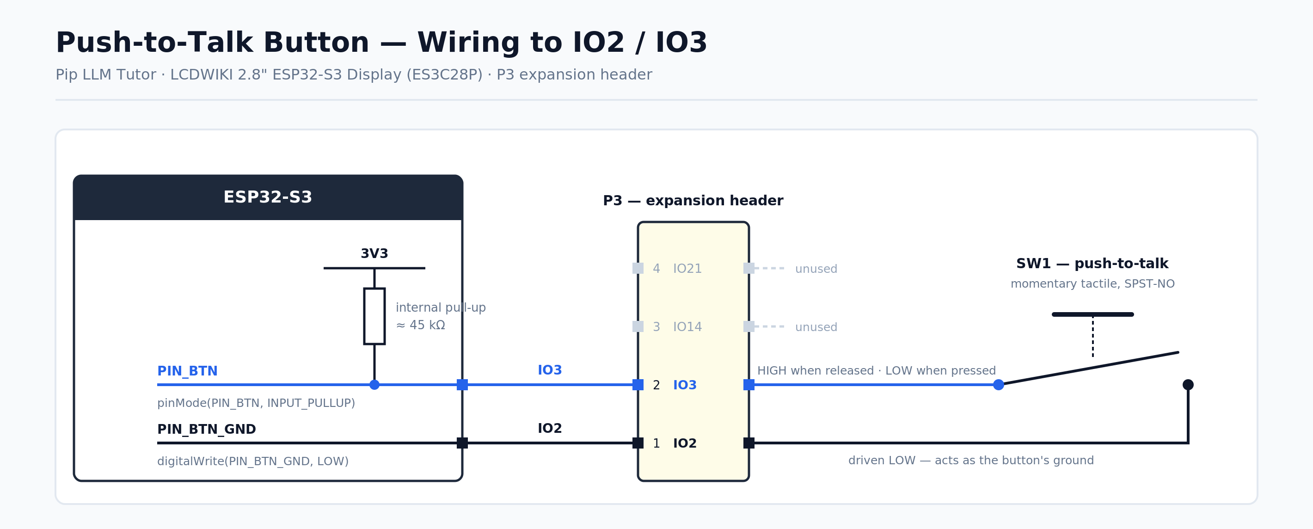
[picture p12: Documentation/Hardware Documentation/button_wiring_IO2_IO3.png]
Push-to-talk button wiring: momentary switch between IO2 and IO3 on the P3 expansion header


### Connections

The switch is wired directly between header pins 1 and 2. It is unpolarised, so either terminal may go to either pin.

P3 pin | Signal | Firmware constant | Mode
1 | IO2 | PIN_BTN_GND | OUTPUT, driven LOW — serves as the button's local ground
2 | IO3 | PIN_BTN | INPUT_PULLUP — reads HIGH when released, LOW when pressed
3 | IO14 | — | Unused
4 | IO21 | — | Unused

No pull-up resistor is fitted: IO3's internal pull-up (approximately 45 kΩ) is enabled in firmware, and IO2 is an ordinary GPIO held LOW so the button can occupy just two header pins instead of borrowing a ground.

### Deep-sleep wake

The same button wakes the device. EXT1 is armed to wake on IO3 going LOW, with IO2 held LOW through the RTC domain so it still acts as ground while the main GPIO drivers are off.

IO3 is a strapping pin with no default pull. The RTC peripheral domain must be kept powered during deep sleep, otherwise the internal pull-up is switched off, IO3 floats LOW and the module wakes the instant it sleeps. The cost is a few microamps of additional sleep current.

### Fallback

If a unit's IO3 expansion line proves unreliable, set PIN_BTN to 0 in pins.h to fall back to the onboard BOOT key (section 7), which already grounds IO0. Note that IO43/IO44 (UART) cannot be used for this: TX idles HIGH and RX is held by the UART peripheral.

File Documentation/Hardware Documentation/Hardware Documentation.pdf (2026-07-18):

# Hardware Documentation

### 2.8inch IPS ESP32-S3 (ES3C28P & ES3N28P) Display Module

### Contents

1. Hardware Overview
2. Display & Touch
3. Core Controller
4. Power Management
5. Audio Subsystem
6. Expansion & Interfaces
7. Controls & Indicators
8. Push-to-Talk Button

## 1. Hardware Overview

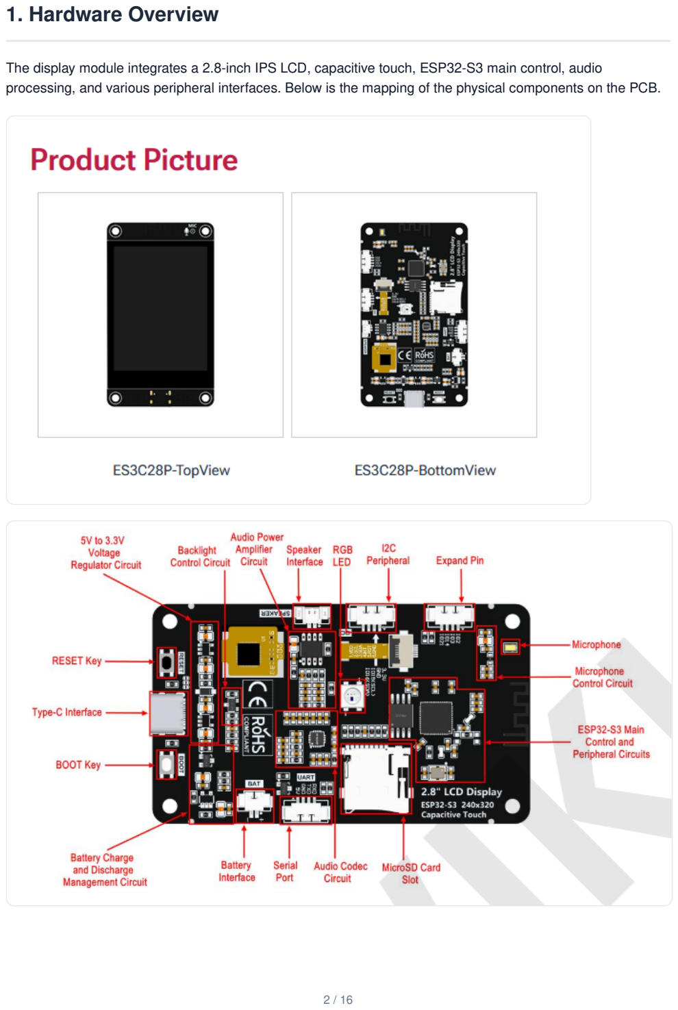
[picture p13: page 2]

The display module integrates a 2.8-inch IPS LCD, capacitive touch, ESP32-S3 main control, audio processing, and various peripheral interfaces. Below is the mapping of the physical components on the PCB.

## 2. Display & Touch

### LCD Screen

The display is a 2.8-inch IPS screen driven by the | ILI9341V | IC with a resolution of 240x320. It connects to
the ESP32-S3 using a 4-wire SPI communication interface. The ILI9341 uses 16 bits (RGB565) to control pixel display, supporting up to 65K colors.

Note: Refer to the ILI9341V datasheet for exact SPI timing diagrams and format structures.

### Capacitive Touch Screen

The touch interface uses the | FT6336G | control IC and communicates with the ESP32-S3 via the I2C bus
(slave address: | 0x38 | ). It connects through a 0.5mm pitch FPC socket using four pins: | CTP_RST | ,
CTP_INT | , | CTP_SDA | , and | CTP_SCL | .

### LCD Backlight Control

Driven by a | BSS138 | N-channel MOSFET. A high level on the | LCD_BL | pin conducts the drain/source,
illuminating the screen. It supports PWM signal input for brightness adjustment.

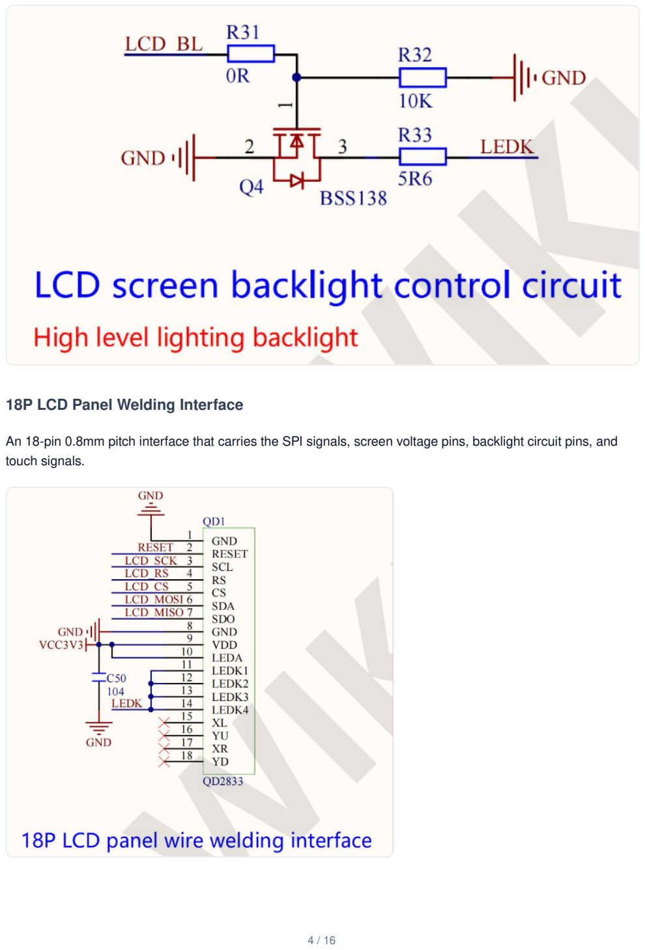
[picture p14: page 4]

### 18P LCD Panel Welding Interface

An 18-pin 0.8mm pitch interface that carries the SPI signals, screen voltage pins, backlight circuit pins, and touch signals.

## 3. Core Controller

The main control chip is the ESP32-S3R8, featuring an Xtensa dual-core 32-bit LX7 microprocessor (up to 240MHz). It includes 8MB of internal OPI PSRAM and connects to an external 16MB QSPI Flash.

Supports 2.4GHz Wi-Fi and Bluetooth V5.0.
Equipped with an onboard PCB antenna circuit.
Utilizes a 40MHz passive crystal oscillator. Includes a CLC filtering circuit for analog power.

•
•
•
•

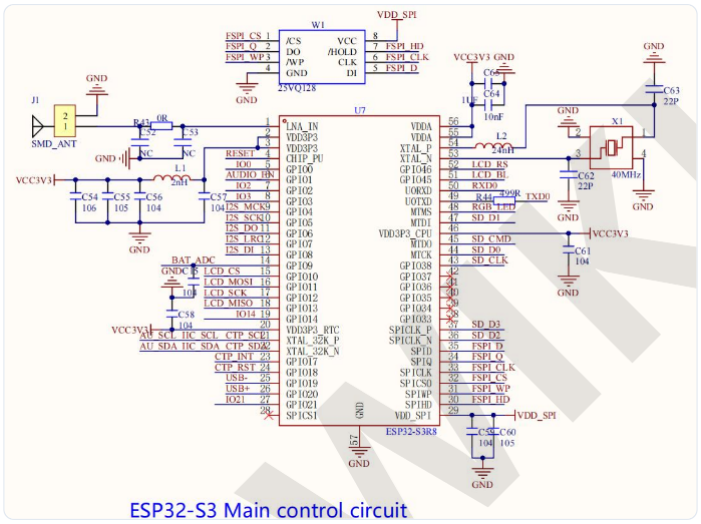
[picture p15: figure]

## 4. Power Management

### Type-C Interface

Provides main power (5V), program downloading, and serial communication. Features a Schottky diode to prevent current reversal and static surge protection diodes.

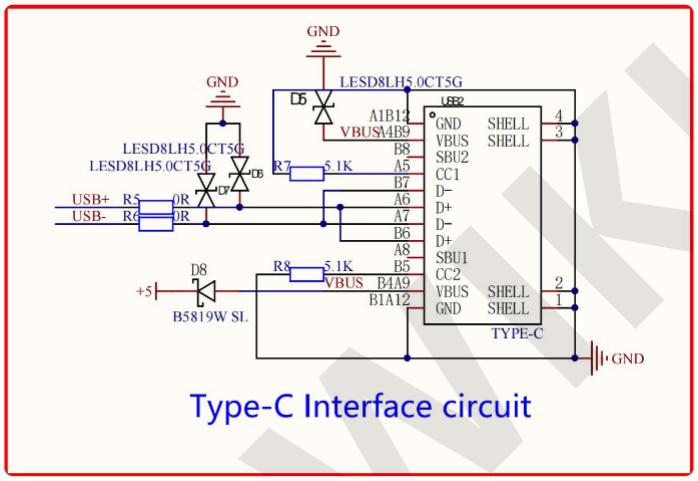
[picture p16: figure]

### 5V to 3.3V Voltage Regulators

Two separate | ME6217C33M5G | LDOs are used (max 800mA output) to isolate power paths: one exclusively for
the audio circuits and one for the rest of the board.

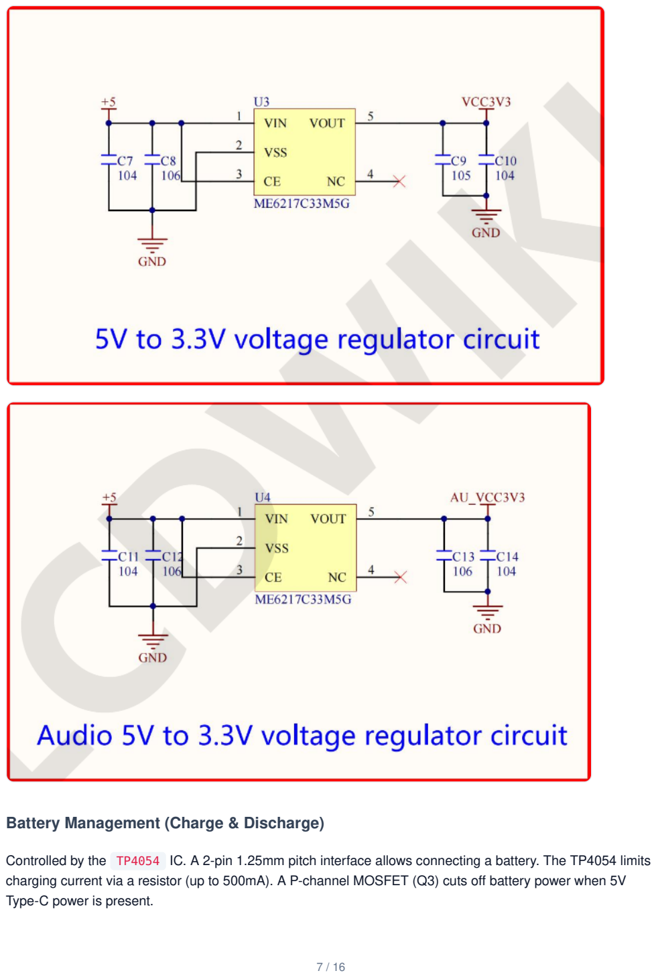
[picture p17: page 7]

### Battery Management (Charge & Discharge)

Controlled by the | TP4054 | IC. A 2-pin 1.25mm pitch interface allows connecting a battery. The TP4054 limits
charging current via a resistor (up to 500mA). A P-channel MOSFET (Q3) cuts off battery power when 5V Type-C power is present.

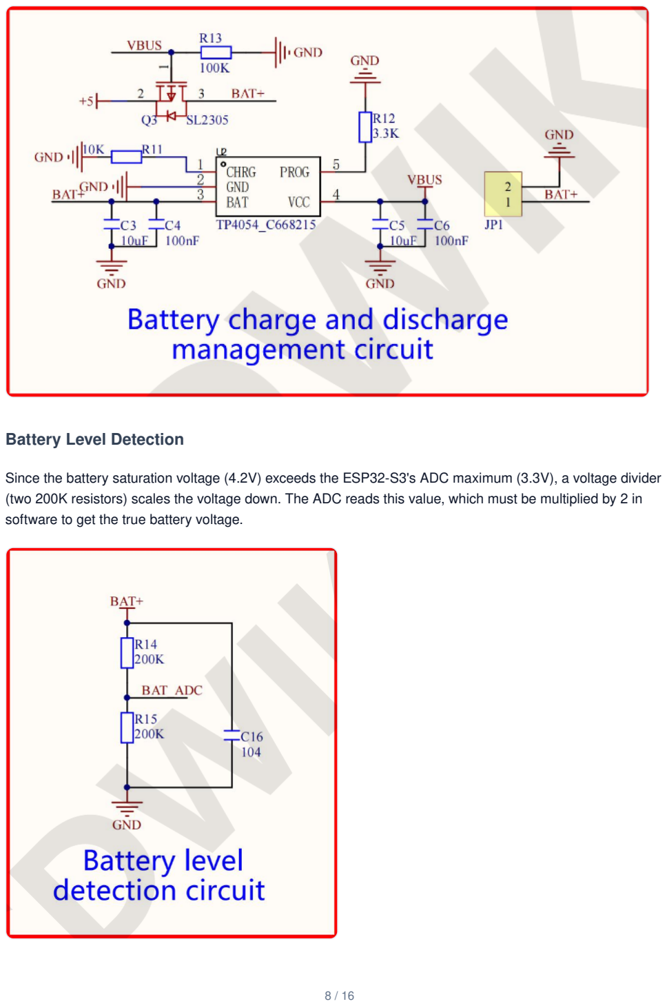
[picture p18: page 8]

### Battery Level Detection

Since the battery saturation voltage (4.2V) exceeds the ESP32-S3's ADC maximum (3.3V), a voltage divider (two 200K resistors) scales the voltage down. The ADC reads this value, which must be multiplied by 2 in software to get the true battery voltage.

## 5. Audio Subsystem

### Audio Codec (ES8311)

The | ES8311 | IC handles decoding and encoding. It is configured via I2C (address | 0x18 | ) and transmits
audio over the I2S bus. It processes incoming MIC signals (via ADC) and outputs audio signals to the amplifier (via DAC).

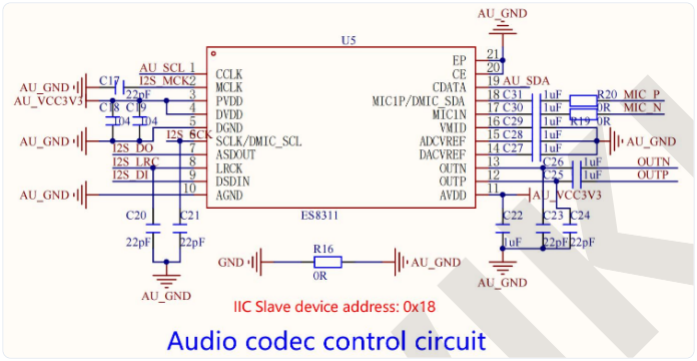
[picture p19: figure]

### Audio Power Amplifier (FM8002E)

The | FM8002E | receives differential signals (OUTP/OUTN) from the codec and amplifies them for the speaker.
At 5V, it can drive 1.5W (8 ohm load) or 2W (4 ohm load). The volume is controlled by gain adjustment resistors.

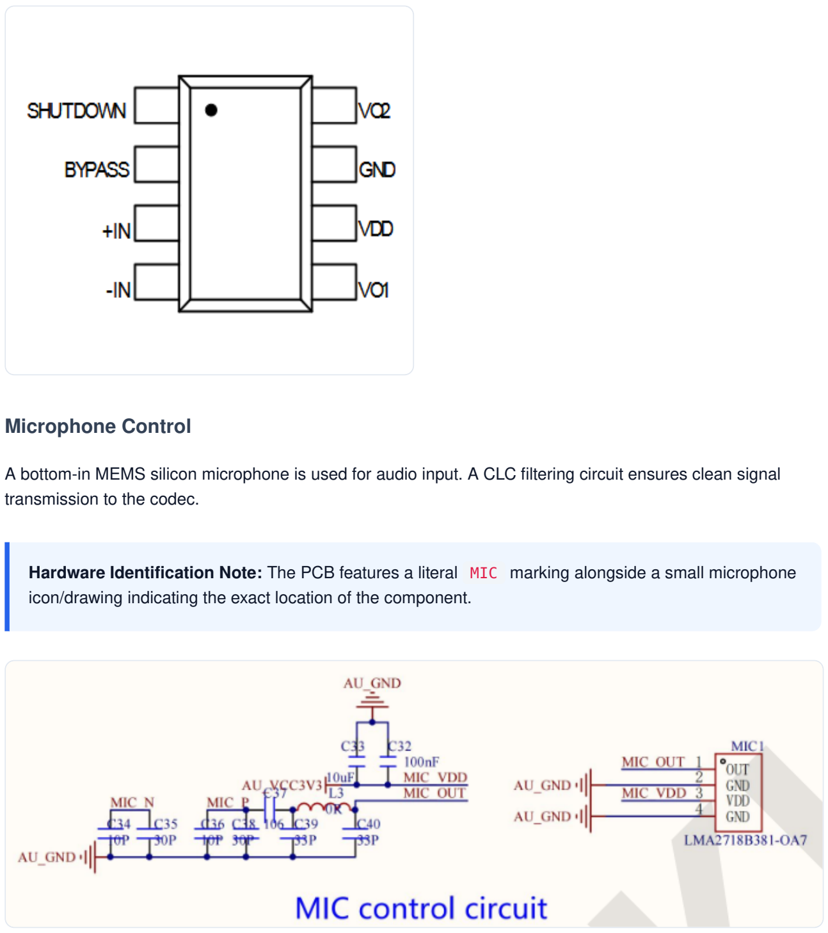
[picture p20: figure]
Microphone Control; transmission to the codec.

A bottom-in MEMS silicon microphone is used for audio input. A CLC filtering circuit ensures clean signal

Hardware Identification Note: The PCB features a literal | MIC | marking alongside a small microphone
icon/drawing indicating the exact location of the component.

## 6. Expansion & Interfaces

### MicroSD Card Slot

Operates using the SDIO communication method rather than standard SPI, allowing for higher-speed storage access.

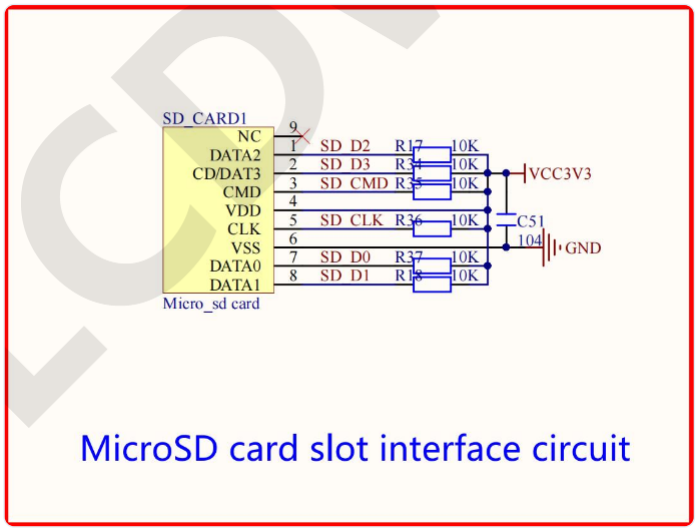
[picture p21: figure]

### Serial Module (UART)

A 4-pin 1.25mm interface exposing RXD0 and TXD0. Features impedance balancing resistors and an anti-reverse field-effect transistor on the 5V line.

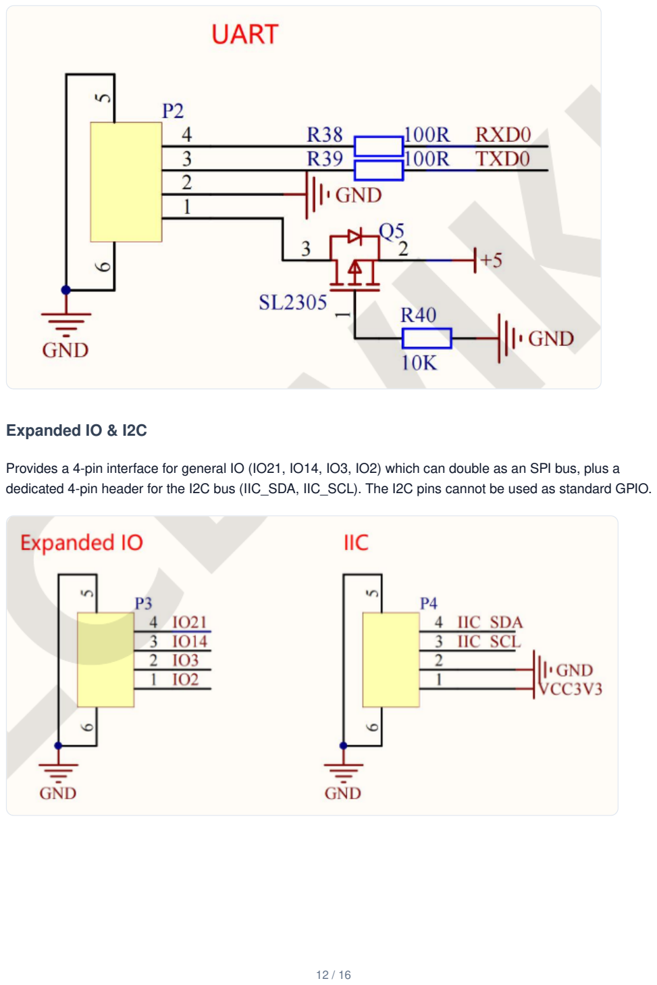
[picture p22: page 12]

### Expanded IO & I2C

Provides a 4-pin interface for general IO (IO21, IO14, IO3, IO2) which can double as an SPI bus, plus a dedicated 4-pin header for the I2C bus (IIC_SDA, IIC_SCL). The I2C pins cannot be used as standard GPIO.

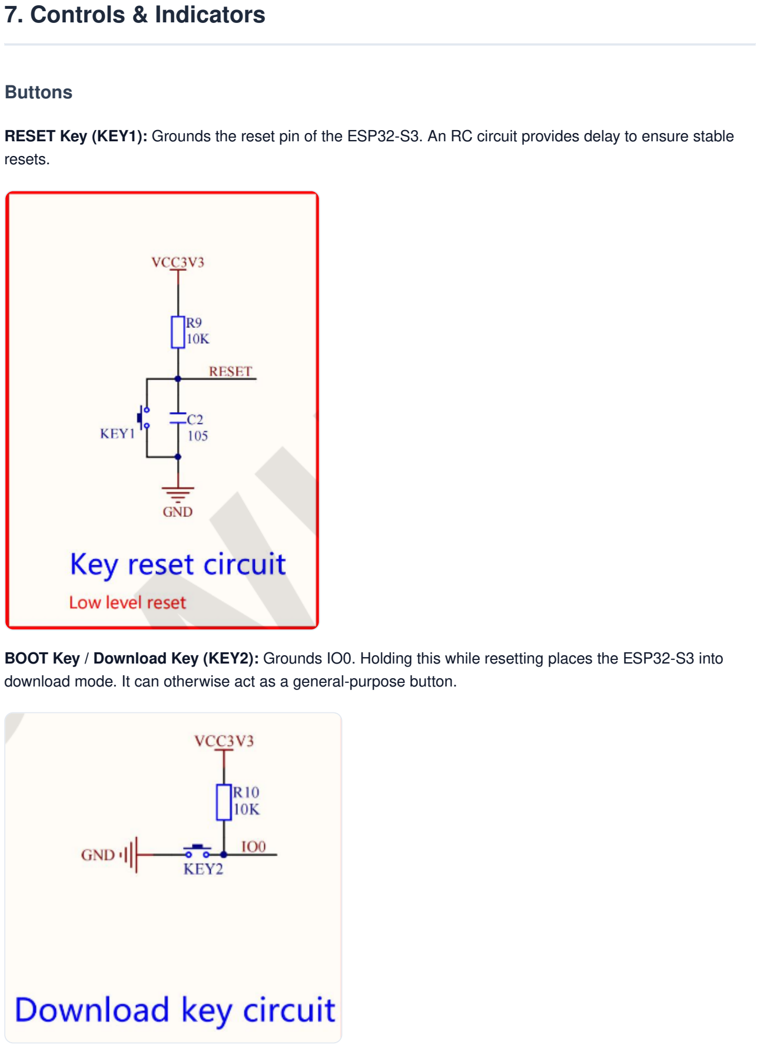
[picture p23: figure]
7. Controls & Indicators; Buttons; resets.

RESET Key (KEY1): Grounds the reset pin of the ESP32-S3. An RC circuit provides delay to ensure stable

BOOT Key / Download Key (KEY2): Grounds IO0. Holding this while resetting places the ESP32-S3 into download mode. It can otherwise act as a general-purpose button.

### RGB LED (WS2812B)

A built-in tri-color RGB LED utilizing an internal IC. Powered by 5V, it requires only a single IO pin to generate different color output based on timing waveforms.

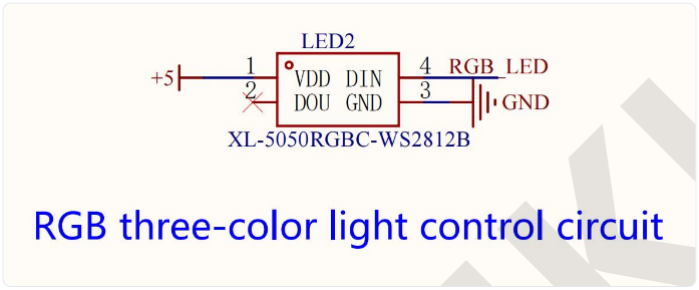
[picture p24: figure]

## 8. Push-to-Talk Button

Sections 1–7 above describe the stock module. This section documents wiring added for the Pip LLM Tutor project: an external momentary button the child holds while answering. It uses two pins of the P3 expanded IO header described in section 6, and needs no external components.

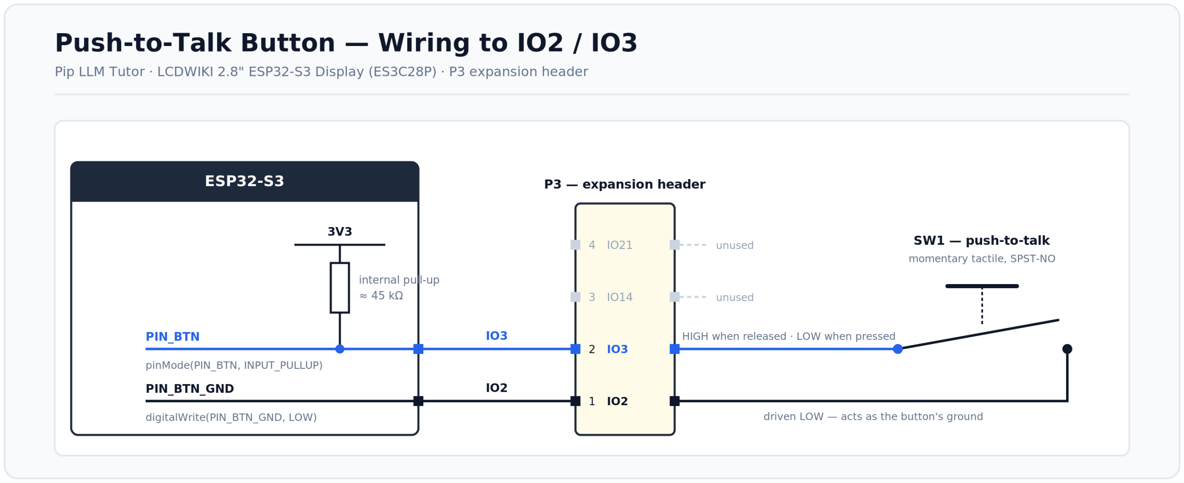
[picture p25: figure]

### Connections

The switch is wired directly between header pins 1 and 2. It is unpolarised, so either terminal may go to either pin.

P3 pin | Signal | Firmware constant | Mode
1 | IO2 | PIN_BTN_GND | OUTPUT , driven LOW — serves as the button's local ground
2 | IO3 | PIN_BTN | INPUT_PULLUP — reads HIGH when released, LOW when pressed
3 | IO14 | — | Unused
4 | IO21 | — | Unused

No pull-up resistor is fitted: IO3's internal pull-up (approximately 45 kΩ) is enabled in firmware, and IO2 is an ordinary GPIO held LOW so the button can occupy just two header pins instead of borrowing a ground.

### Deep-sleep wake

The same button wakes the device. | EXT1 | is armed to wake on IO3 going LOW, with IO2 held LOW through
the RTC domain so it still acts as ground while the main GPIO drivers are off.

IO3 is a strapping pin with no default pull. The RTC peripheral domain must be kept powered during deep sleep, otherwise the internal pull-up is switched off, IO3 floats LOW and the module wakes the instant it sleeps. The cost is a few microamps of additional sleep current.

### Fallback

If a unit's IO3 expansion line proves unreliable, set | PIN_BTN | to | 0 | in | pins.h | to fall back to the onboard
BOOT key (section 7), which already grounds IO0. Note that IO43/IO44 (UART) cannot be used for this: TX idles HIGH and RX is held by the UART peripheral.

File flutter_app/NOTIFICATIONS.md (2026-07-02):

# Push notifications setup

The parent app delivers three push notifications via Firebase Cloud Messaging (FCM):

| Trigger | When |
|---|---|
| **`<name> התחיל/ה שיעור`** | Cloud Function fires on `sessions/{id}` create |
| **`<name> סיים/ה את השיעור`** | Scheduled function marks the session ended after 5 min of no exchange, then notifies |
| **`ההתקן של <name> מנותק`** | Scheduled function detects `deviceState/{id}.lastHeartbeat` older than 60 s, dedups per offline period |

Logic lives in `firebase/functions/notifications.js`. Hebrew verb forms use the child's `gender` field (boy/girl).

---

## One-time setup (do these once per project)

### 1. Generate a Web Push VAPID key

1. Open **[Firebase Console → Project Settings → Cloud Messaging](https://console.firebase.google.com/project/llm-tutor-d721e/settings/cloudmessaging)**
2. Scroll to **Web configuration → Web Push certificates → Generate key pair**
3. Copy the **public key** (looks like `B...`, ~88 chars)
4. Paste it into `lib/constants.dart`:
   ```dart
   static const String fcmVapidKey = 'B...'; // your public key here
   ```
5. Rebuild + redeploy the web app: `flutter build web --release --pwa-strategy=none && firebase deploy --only hosting`

Without this, **Android push still works** but **web push silently fails** (the `getToken` call returns null on web).

### 2. Enable Cloud Scheduler API

The `monitorTutor` function runs on a schedule (every minute). Cloud Scheduler must be enabled in the GCP project:

1. Open **[GCP Console → APIs → Cloud Scheduler API](https://console.cloud.google.com/apis/library/cloudscheduler.googleapis.com?project=llm-tutor-d721e)**
2. Click **Enable**

First-time deploy will fail with a clear "Enable Cloud Scheduler" error if you skip this step.

### 3. Deploy the Cloud Functions

```bash
cd firebase/functions
firebase deploy --only functions
```

This adds `notifyOnSessionStarted` and `monitorTutor` alongside the partner's existing tutor functions.

---

## Schema additions

```
parents/{uid}.fcmTokens: array<string>       # written by the Flutter app on attach
deviceState/{deviceId}.notifiedOfflineAt: timestamp   # written by monitorTutor to dedupe
sessions/{id}.endedAt: timestamp              # written by monitorTutor when ending by inactivity
sessions/{id}.status: "ended"                 # same — partner's tutor sets "active", we transition to "ended"
```

Firestore rules already allow the parent to write their own `parents/{uid}` doc (`request.auth.uid == parentId`), so the token registration goes through with no rule change.

---

## How it works end-to-end

1. Parent signs into the app. `FcmService.attach(uid)` is called from `main.dart`'s auth listener.
2. The service asks the OS for notification permission, fetches an FCM token, and writes it via `addParentFcmToken` (array union, idempotent).
3. The token rotates occasionally → `onTokenRefresh` keeps Firestore in sync.
4. Parent signs out → `detach()` removes the token from the array so notifications stop reaching this device.
5. The partner's ESP32 creates a session → `notifyOnSessionStarted` fires → reads the parent's tokens → sends FCM to each → OS shows the notification (or the foreground SnackBar via `onForegroundMessage` if the app is open).
6. Same flow for the scheduled triggers: every 60 s, check active sessions for inactivity (5 min no exchange) and devices for stale heartbeats.

Dead tokens (uninstall, cleared cookies) are pruned automatically — the send function catches `messaging/registration-token-not-registered` and removes the token from the array.

---

## Files added / changed

| Path | Purpose |
|---|---|
| `firebase/functions/notifications.js` | The three triggers + the send helper |
| `firebase/functions/index.js` | Re-exports the two new functions |
| `lib/constants.dart` | `fcmVapidKey` placeholder |
| `lib/services/firebase_service.dart` (+ `_real.dart`) | `addParentFcmToken` / `removeParentFcmToken` |
| `lib/services/fcm_service.dart` | Permission, token, refresh, foreground callback |
| `lib/main.dart` | Wires FCM to the auth lifecycle |
| `web/firebase-messaging-sw.js` | Background service worker for browser push |

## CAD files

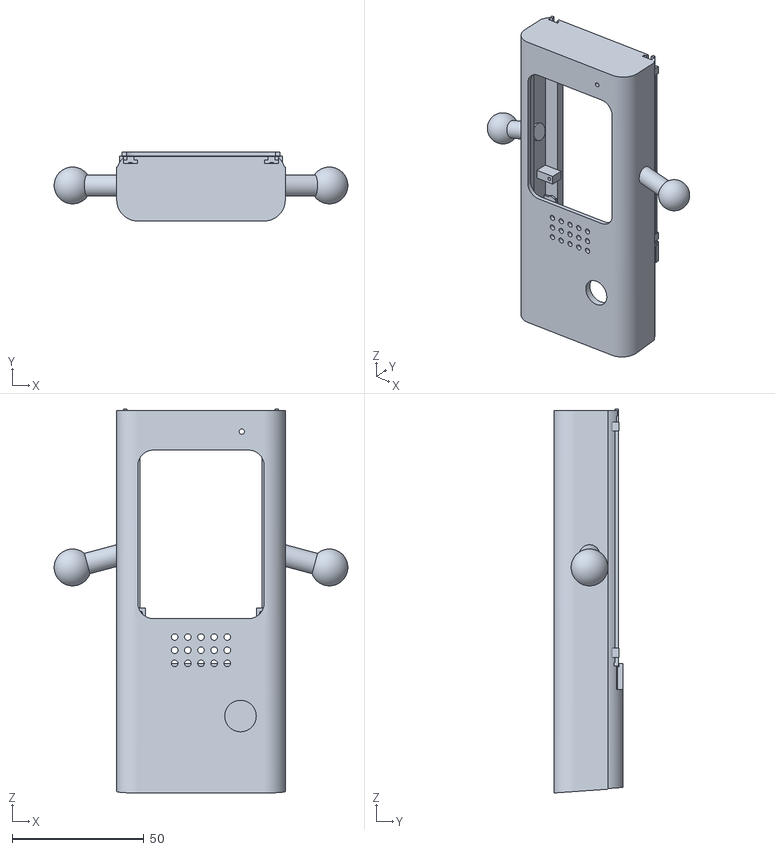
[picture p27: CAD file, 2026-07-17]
Assets/3D/pip_main_body.stl
111.5 x 26.2 x 145.8

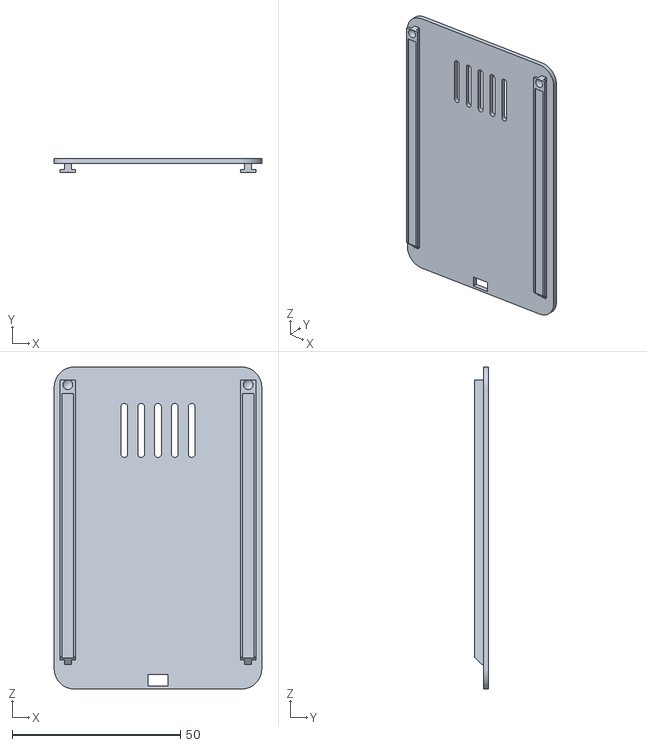
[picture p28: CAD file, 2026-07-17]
Assets/3D/pip_rear_cover.stl
61.7 x 4.15 x 95.7

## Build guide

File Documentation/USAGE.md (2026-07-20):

# Usage Instructions

How to operate Pip day-to-day. For building/flashing the firmware and deploying
the cloud side, see [INTEGRATION.md](INTEGRATION.md).

## First-time setup (pairing)

1. Power the device over USB-C. Pip's face appears and the device connects to
   WiFi (credentials from `secrets.h`).
2. An **unpaired** device shows its pairing code on screen: `TUTOR-XXXXXX`
   (also printed to the Serial Monitor at every boot).
3. In the parent app (https://llm-tutor-d721e.web.app or the Android APK):
   sign in → add/select a child → enter the pairing code under the device
   section. Pairing is "newest wins" — re-pairing to another child automatically
   unlinks the previous one; no unpair step is needed.
4. Reboot the device (or wait for the session to end). It picks up the paired
   child and greets them by name.

## Daily use

1. Power on. The device auto-starts a tutoring session for the paired child and
   **speaks the first question** (face: speaking).
2. The child **holds the push-to-talk button** (the physical button on the
   device), answers out loud, and **releases** (max recording ~7 s).
3. Pip grades the answer, speaks feedback + the next question, and its face
   reacts to how the child is doing. Correct answers add stars on the strip.
4. Progress, mood and accuracy reports appear in the parent app; homework
   materials uploaded in the app are turned into questions automatically.

**Auto power-off (idle policy):** after a period with no interaction the screen
turns off, and later the device enters deep sleep ("off"). Both thresholds are
set per-child in the app (Settings → auto power-off). **A button press wakes the
device.**

## Main error indications

| What you see | Meaning | What to do |
|---|---|---|
| Face shows **error** status shortly after boot | WiFi could not connect (~20 s without a link; device keeps retrying by itself) | Check the router / hotspot and the `WIFI_SSID`/`WIFI_PASSWORD` in `secrets.h` |
| Serial: `❌ Firebase auth failed` + error face | Wrong/expired `FIREBASE_WEB_API_KEY` in `secrets.h` | Copy the Web API Key from Firebase Console → Project Settings |
| Serial: `Not ready to start (unpaired or a transient error) — retrying in 15s` | Device is not paired to any child, or a transient cloud error | Pair it in the app (see above); transient errors resolve on their own |
| Pip re-asks the same question after a long pause | The answer upload failed mid-turn (WiFi hiccup / backend timeout) | Nothing — the device re-prompts automatically; just answer again |
| Serial: `⚠️ pip_face init failed` (audio still works) | Display init problem (TFT_eSPI `User_Setup` not copied, or PSRAM not enabled in the IDE board settings) | See [INTEGRATION.md](INTEGRATION.md) — copy `pip_face/User_Setup_LCDWIKI.h` and set PSRAM to "OPI PSRAM" |
| Serial: `⚠️ ES8311 init failed. Audio may not work.` | Audio codec did not answer on I2C | Power-cycle the board; verify it's the LCDWIKI ES3C28P/ES3N28P board |
| App shows the device as offline | No heartbeat for >30 s | Device is asleep/unpowered or lost WiFi — press the button / check power and network |

The device is deliberately self-healing: WiFi retries forever, session start
retries every 15 s, and failed turns re-prompt — power-cycling is the universal
fallback.

## Parent-app error messages

All app errors are shown in Hebrew, in-context:

| Message | Meaning | What to do |
|---|---|---|
| «אימייל או סיסמה שגויים» / «כתובת אימייל לא תקינה» | Wrong sign-in credentials / malformed email | Fix and retry; use "forgot password" for a reset email |
| «האימייל כבר רשום במערכת» | Sign-up with an email that already has an account | Sign in instead |
| «האימייל כבר רשום עם סיסמה. התחברו עם אימייל וסיסמה» | Tried Google Sign-In for an account created with email+password | Sign in with the original method |
| «הסיסמה חלשה מדי (לפחות 6 תווים)» | Password under 6 characters at sign-up | Choose a longer password |
| «אין חיבור לאינטרנט» + offline banner | The app itself lost connectivity | Restore network; queued writes sync automatically |
| «לא נמצא התקן עם הקוד הזה. ודאו שהמכשיר דולק ומחובר ל-Wi-Fi.» | Pairing code doesn't match any registered device | Check the `TUTOR-XXXXXX` code on the device screen; make sure it booted and reached WiFi at least once |
| «ההתקן נמצא, אבל לא דיווח עדכני. ודאו שהוא דולק ונסו שוב בעוד רגע.» | Device exists but its heartbeat is stale (>60 s) — probably off or offline right now | Power the device, wait a few seconds for a heartbeat, retry pairing |
| «לא נמצאו שאלות במסמך. נסה קובץ ברור יותר.» | Uploaded homework file yielded no extractable questions | Upload a clearer photo/scan of the material |
| «עיבוד השאלות נכשל. נסה שוב.» / «העלאת הקובץ נכשלה» | Cloud extraction or the upload itself failed (transient) | Retry; check connectivity |
| «נחסם — תוכן לא מתאים, לא ניתן לכלול בתרגול» | Material failed validation (not age/subject-appropriate) — its toggle is locked | Upload material matching the child's age and the selected subject |
| Device badge shows «לא מחובר» | No device heartbeat for >30 s | Device asleep/unpowered or lost WiFi — press its button / check power and network |

## Calibration

**No manual calibration is required.**

- **Microphone** — input gain is automatic (auto-gain up to +21.6 dB targeting
  ~−3.4 dBFS; see `MIC_TARGET_PEAK` / `MIC_MAX_GAIN` in
  [Parameters](../Parameters/README.md)).
- **Speaker volume** — fixed at compile time (`es8311.h` DAC volume register,
  default ~+3 dB).
- **Touch screen** — the FT6336G is capacitive and needs no calibration.

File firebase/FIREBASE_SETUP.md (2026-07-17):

# Firebase Setup Guide

How to wire up a Firebase project for Pip from scratch. (For day-to-day deploy
commands see `Documentation/INTEGRATION.md`; for the full Firestore schema see
`Documentation/LLM_INTERFACE.md`.)

---

## Architecture Overview

```
ESP32 (mic + speaker + display)
  │
  │  ONE HTTPS call per turn (raw PCM16 audio upload)
  ▼
Cloud Function processTurn  ──►  Google STT (transcribe)
  │                         ──►  Gemini 2.5 Flash via Vertex AI (grade + feedback + next question)
  │                         ──►  Google TTS (he-IL audio, returned inline as the HTTP body)
  │
  ├─► writes the turn + session stats to Firestore
  ▼
Firestore  ◄── realtime streams ──►  Flutter parent app (reports, materials, pairing)
```

Supporting functions: `onSessionCreated` (first question + TTS when a session
doc appears), `extractQuestionsFromMaterial` (turns uploaded homework files
into validated Q&A via Gemini), `enforceDeviceUniqueness` (one device ↔ one
child, newest pairing wins), `notifyOnSessionStarted`/`monitorTutor` (FCM push
+ monitoring), `transcribeAudio`/`synthesizeSpeech`/`ttsBytes` (STT/TTS
proxies), and a legacy post-and-poll path (`answerQuestion`,
`startLearningSession`, `submitChildAnswer`) kept as an A/B fallback
(`USE_PROCESS_TURN 0` in the firmware).

---

## Step 1: Firebase Console Setup

Go to [console.firebase.google.com](https://console.firebase.google.com) and create/open a project.

### 1a. Firestore
- **Build → Firestore Database → Create database**, Production mode.
- Region close to you (this project: `eur3`/European region).

### 1b. Authentication
- **Build → Authentication → Get started**.
- Enable **Anonymous** (the ESP32 signs in anonymously and persists its
  refresh token in flash, so its UID is stable across reboots).
- Enable **Email/Password** and **Google** (the Flutter parent app supports both).

### 1c. Cloud Functions
- **Build → Functions → Get started**.
- ⚠️ Requires the **Blaze (pay-as-you-go)** plan. At this project's scale the
  cost is essentially $0, but a billing account is required.
- **Region:** all functions deploy to **`europe-west10`** (set via
  `setGlobalOptions` in `functions/index.js`). The ESP32
  (`CLOUD_FUNCTIONS_REGION` in `secrets.h`) and the Flutter app
  (`AppConstants.functionsRegion`) must match. If `firebase deploy` rejects the
  region for a Firestore-trigger function (Eventarc availability varies), set
  `FUNCTIONS_REGION` to a nearby supported region and update both client
  constants.

### 1d. Enable Google Cloud APIs
In the [Google Cloud console](https://console.cloud.google.com) for the same
project, enable:
- **Vertex AI API** (Gemini — no API key needed; functions use the project's
  service account, so there is no LLM key/secret to manage)
- **Cloud Speech-to-Text API**
- **Cloud Text-to-Speech API**
- **Firebase Storage** (uploaded homework files + generated TTS audio)

---

## Step 2: Install the Firebase CLI

```bash
npm install -g firebase-tools
firebase login
```

---

## Step 3: Set Your Project ID

Edit `firebase/.firebaserc` and set your project ID (Firebase console →
Project Settings → General):

```json
{
  "projects": { "default": "your-actual-project-id" }
}
```

---

## Step 4: Deploy

```bash
cd firebase/
npm install --prefix functions

# Functions discovery is heavy — without these flags deploy can OOM/time out:
NODE_OPTIONS="--max-old-space-size=8192" FUNCTIONS_DISCOVERY_TIMEOUT=540 \
  firebase deploy    # functions + firestore rules/indexes + storage rules
```

Optional env overrides (Functions → configuration): `GEMINI_MODEL`
(default `gemini-2.5-flash`), `GEMINI_LOCATION` (default `global`),
`FUNCTIONS_REGION`.

---

## Step 5: Firestore Data Model (summary)

```
parents/{parentId}                    ← app writes (account profile)
children/{childId}                    ← app writes (profile, settings, deviceId pairing)
materials/{materialId}                ← app writes; extractQuestionsFromMaterial fills items[]
pairingCodes/{TUTOR-XXXXXX}           ← device registers its code → firebaseUid
deviceState/{deviceUid}               ← device writes status + heartbeat; app reads
sessions/{sessionId}                  ← device creates; functions + device write turns/stats
  questions/ (subcollection)          ← one doc per Q&A turn
```

Full field-by-field schema: `Documentation/LLM_INTERFACE.md`.

---

## Step 6: Device Auth (already implemented in the firmware)

The ESP32 has no Firebase SDK — it uses the REST APIs:

1. First boot: `accounts:signUp` (anonymous) with the **Web API Key** from
   `secrets.h` → receives `idToken` + `refreshToken`.
2. The `refreshToken` + UID are persisted in NVS flash, so the device keeps a
   **stable UID** across reboots (this UID is what a child's `deviceId` links
   to when pairing).
3. Every boot: the token is refreshed via `securetoken.googleapis.com`.

No manual token work is needed — `ESP32/homework_assistant/firebase_client.h`
does all of this.

---

## Setup checklist

- [ ] Firestore + Auth (Anonymous, Email/Password, Google) + Functions (Blaze) enabled
- [ ] Vertex AI, STT, TTS, Storage APIs enabled in Google Cloud
- [ ] `.firebaserc` project ID set
- [ ] `firebase deploy` succeeded (with the NODE_OPTIONS flags)
- [ ] `ESP32/homework_assistant/secrets.h` filled in (Web API Key, project ID, region)
- [ ] Flutter app: `flutterfire configure` run against the same project

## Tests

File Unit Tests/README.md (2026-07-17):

# Unit Tests

Validation sketches for the individual hardware components. Flash each one on
its own (Arduino IDE, same board settings as the main firmware) to verify a
part in isolation — useful for elimination-style debugging when something
stops working.

| Sketch | What it tests |
|---|---|
| `test_esp32_upload/` | Board + toolchain sanity — verifies the ESP32-S3 flashes and runs at all |
| `test_button/` | Push-to-talk button wiring (IO2↔IO3, `INPUT_PULLUP`, active LOW) |
| `test_display_touch/` | ILI9341 display + FT6336G capacitive touch (SPI + I2C) |
| `test_microphone/` | ES8311 codec ADC path — captures audio from the onboard mic over I2S |
| `test_speaker/` | ES8311 codec DAC path — plays audio through the FM8002E amp + speaker |

Cloud-side test utility: `firebase/functions/mock_pair.js` simulates an
app→child pairing from the terminal (no second phone needed) — see its header
comment for usage.

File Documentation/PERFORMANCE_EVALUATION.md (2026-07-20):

# Performance Evaluation — Pip LLM Tutor

Quantitative evaluation of the project's main algorithm — the **turn-processing
pipeline** — with the measured results and the method used to obtain them. The
hop-by-hop design analysis lives in [LATENCY.md](LATENCY.md); the source chart is
[latency-results.pdf](latency-results.pdf).

---

## 1. What was evaluated

A tutoring "turn" runs this pipeline on every answer:

```
record answer → STT → grade (deterministic + answer variants) → adaptive difficulty
             → gated Gemini feedback (only when it adds value) → TTS → play
```

The key algorithmic decisions evaluated:

1. **Latency of the whole pipeline** — the user-perceived metric that matters for
   a child: *record-end → robot starts speaking the feedback.*
2. **The LLM gating algorithm** — Gemini is called only on wrong answers or long
   streaks (`needsLLM` gate); simple correct answers use deterministic feedback.
   This trades a small quality cost for a large latency/cost saving.

## 2. Experimental setup (test conditions)

| Parameter | Value |
|---|---|
| Device | ESP32-S3 (LCDWIKI 2.8" board), firmware built for this project |
| Network | Home Wi-Fi, Israel |
| Cloud | Firebase Cloud Functions in `europe-west10` (Berlin), warm (`minInstances: 1`) |
| Metric | Wall-clock `RECORD → FIRST_SOUND` (button release → first audio sample out) |
| Instrumentation | Device-side `millis()` deltas printed as `[lat]` serial logs (see `homework_assistant.ino`, and §"How to measure" in LATENCY.md) |
| Turn types | Correct answer (no LLM) and wrong answer (Gemini hint), warm path |
| Date | Measured 2026-06-29 |

The same metric was captured for each configuration in the table below, so the
effect of each change is isolated.

## 3. Results — latency by configuration

| Configuration | Key characteristics | Correct | Wrong (Gemini) | Net hops |
|---|---|---|---|---|
| WAV over URL | full uncompressed WAV downloaded before playback | ~20 s † | — | 5 |
| MP3 over URL | write→trigger→poll→download | **14.8 s** | 17–19 s | 5 |
| + warm config | `minInstances`, `preferRest`, `thinkingBudget:0`, keep-alive poll | 10.8 s | 12.5 s | 5 (warm) |
| + single-call turn | one synchronous `processTurn` (grade + gated Gemini + TTS inline); SD-cached prompts | 6.3–6.6 s | 7–8.3 s | 2 |
| **+ server-side STT (current)** | raw PCM uploaded to `processTurn`; keep-alive heartbeat | **4.0–4.3 s** | 5.8 s | 1 |

† Not instrumented (timers were added at the MP3 baseline).

**Headline:** 14.8–19 s → **4.0–5.8 s**, a **~3.5× speed-up** (10–13 s cut per
turn). Network round-trips per turn dropped **5 → 1**; inline-audio decode dropped
from a **2.6–3.8 s** URL download to **2–4 ms**.

### Where the baseline 14.8 s went (measured, per stage)

The original MP3-URL baseline, broken down by stage on three real turns (device
`[lat]` timers) — this is what the optimisation had to remove:

| Stage | Turn 1 "milk" (correct, no LLM) | Turn 2 "SCH" (wrong, LLM) | Turn 3 "Joshua" (wrong, LLM) | Doc estimate |
|---|---|---|---|---|
| B — STT | 4.02 s | 2.83 s | 3.29 s | 1.5–3.0 s |
| C — post write | 2.27 s | 2.25 s | 2.08 s | 0.4–0.8 s |
| D+E+F — trigger + compute + poll | 2.27 s | 4.64 s | 4.40 s | 1.8–4.8 s |
| G — audio download + decode | 2.60 s | 3.04 s | 3.75 s | 0.7–1.2 s |
| Gap (2 unmeasured device-state writes) | ~3.65 s | ~4.20 s | ~5.50 s | not in doc |
| **RECORD → FIRST SOUND** | **14.8 s** | **17.0 s** | **19.0 s** | 5.4–9.8 s |

Gap = total − the four measured stages; it's the two `firestoreWriteDeviceState`
writes (local preprocessing is sub-100 ms). The single-call design collapses
B+C+D+E+F+the writes into one `processTurn` request — which is why the
current-configuration figures below land near 4 s.

## 4. Results — current configuration measured live on hardware

Three consecutive real turns (the raw `[lat]` output):

| Turn | Answer | Path | processTurnAudio | Decode | **RECORD→SOUND** |
|---|---|---|---|---|---|
| 1 | "sister" ✓ | grade only | 4341 ms | 2 ms | **4343 ms** |
| 2 | "milk" ✓ (streak) | grade only | 4066 ms | 4 ms | **4073 ms** |
| 3 | "no idea" ✗ | grade + Gemini hint | 5841 ms | 2 ms | **5843 ms** |

**Interpretation:** the remaining ~4 s on a correct turn is essentially the single
STT + compute + TTS round trip Israel↔Berlin — close to the practical floor
without changing region. Turn 3's extra ~1.5 s is the (correctly gated) Gemini
hint call — i.e. the gating algorithm keeps the common correct-answer path off the
LLM, saving ~1.5 s and one API call on the majority of turns.

## 5. Correctness of the grading algorithm

Answers are graded by a deterministic pipeline (normalisation → accepted answer
variants → filler stripping → spoken-Hebrew number parsing → cross-script
phonetic matching) before any LLM call. The pipeline is covered by an automated
test suite committed at `firebase/functions/test/run_tests.js` (run with
`npm test` from `firebase/functions/`):

| Test group | What it verifies | Cases |
|---|---|---|
| Exact / variant / filler | digits, Hebrew number words, lead-in phrases | 8 |
| Spoken Hebrew numbers | 0–999, both genders, tens+units, teens, hundreds — plus non-matches (9 ≠ 19, 24 ≠ 240) | 27 |
| Cross-script phonetic | English answered in Hebrew letters ("רד" ↔ red) across the vocabulary bank, with false-positive guards | 60 |
| Generator self-consistency | every generated question (both subjects × 10 difficulty levels) has a non-empty prompt/answer, the answer grades correct against itself, and math prompts are re-parsed to verify the arithmetic | ~1,400 |

**Result: 1,499 assertions, 100% pass.** Each graded turn is also logged in
`sessions/{id}/questions` (prompt, expected answer, transcript, correct/wrong),
so grading decisions can be reviewed against the child's actual transcript.

## 6. Reproducing the measurement

1. Flash the firmware with the `[lat]` logging enabled (already in
   `processCapturedAnswer()` / the main turn path).
2. Open the Arduino Serial Monitor; answer several questions (mix correct and
   wrong) on a warm session.
3. Read the `[lat] === turn: … RECORD->FIRST_SOUND=… ms ===` summary line per
   turn; average correct-answer and wrong-answer turns separately.
4. For cloud-side timing, the Functions logs show per-invocation execution time.

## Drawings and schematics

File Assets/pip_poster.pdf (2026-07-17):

# Personal Assistant with LLM

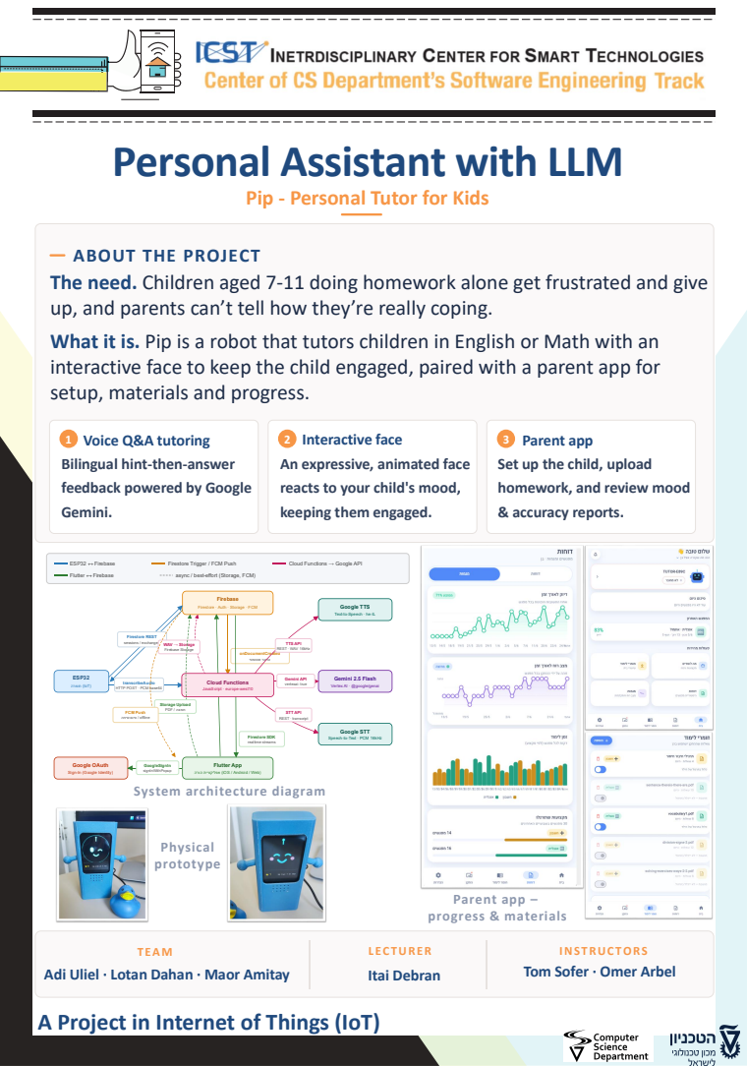
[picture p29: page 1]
Physical prototype; L E C T U R E R Itai Debran; Parent app – progress & materials

Pip - Personal Tutor for Kids

ABOUT THE PROJECT
The need. Children aged 7-11 doing homework alone get frustrated and give
up, and parents can’t tell how they’re really coping.
What it is. Pip is a robot that tutors children in English or Math with an
interactive face to keep the child engaged, paired with a parent app for
setup, materials and progress.

1 Voice Q&A tutoring
Bilingual hint-then-answer
feedback powered by Google
Gemini.

2 Interactive face
An expressive, animated face
reacts to your child's mood,
keeping them engaged.

3 Parent app
Set up the child, upload
homework, and review mood
& accuracy reports.

System architecture diagram

Tom Sofer · Omer Arbel

Adi Uliel · Lotan Dahan · Maor Amitay
A Project in Internet of Things (IoT)

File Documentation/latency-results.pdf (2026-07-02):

# Pip Tutor — Turn Latency

Record-end → robot starts speaking the feedback. ESP32-S3, home Wi-Fi (Israel),

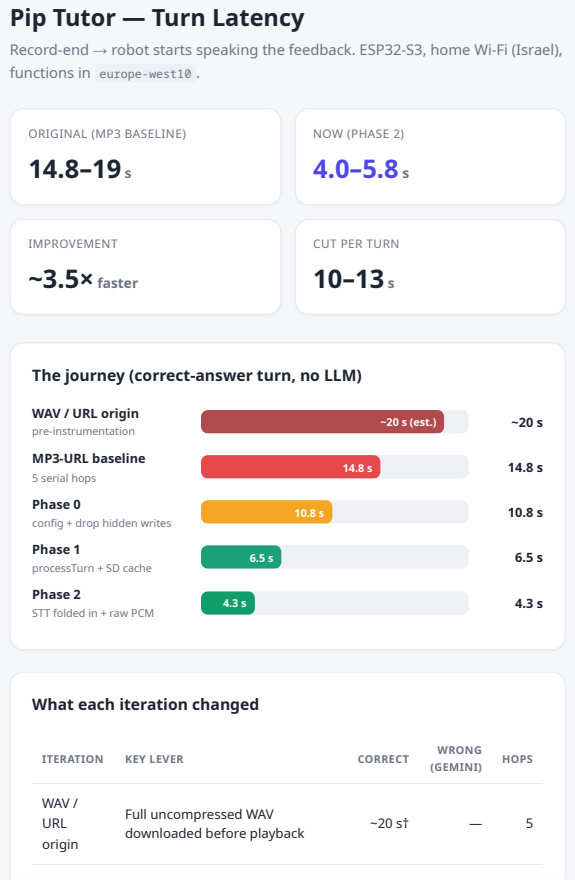
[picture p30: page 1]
ORIGINAL (MP3 BASELINE) 14.8–19s; NOW (PHASE 2) 4.0–5.8s; IMPROVEMENT ~3.5×faster; ~20 s (est.); ITERATION; KEY LEVER; CORRECT; WRONG (GEMINI); HOPS; WAV / URL origin

functions in europe-west10 .

CUT PER TURN

The journey (correct-answer turn, no LLM)

WAV / URL origin
pre-instrumentation
MP3-URL baseline
5 serial hops
Phase 0
config + drop hidden writes
Phase 1
processTurn + SD cache
Phase 2
STT folded in + raw PCM

What each iteration changed

Full uncompressed WAV
downloaded before playback

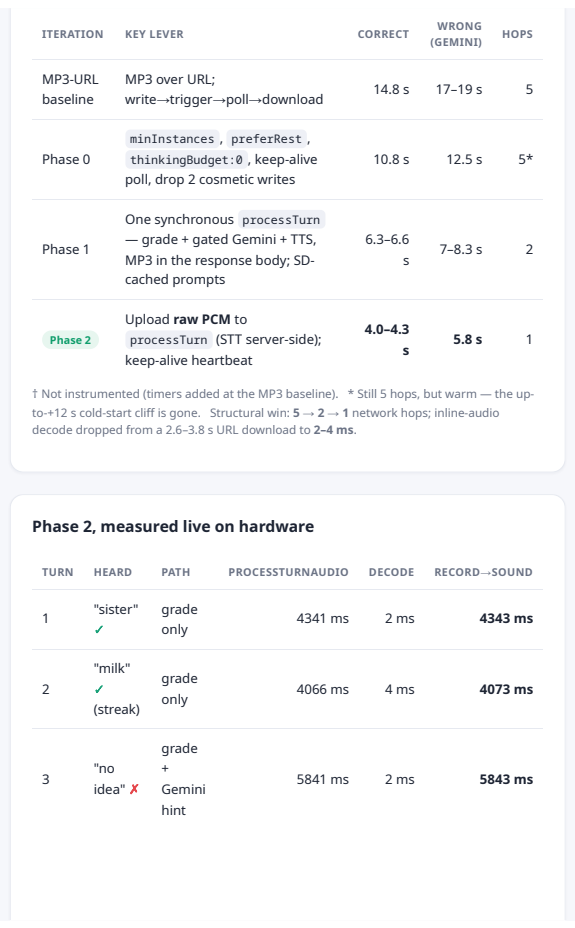
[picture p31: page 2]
ITERATION; KEY LEVER; CORRECT; WRONG (GEMINI); HOPS; MP3-URL baseline; Phase 0; Phase 1; Phase 2; TURN; HEARD; PATH; PROCESSTURNAUDIO; DECODE; RECORD→SOUND; "sister"; grade only; "milk"; ✓ (streak); "no idea" ✗; grade + Gemini hint

MP3 over URL;
write→trigger→poll→download

minInstances , preferRest ,
thinkingBudget:0 , keep-alive
poll, drop 2 cosmetic writes

One synchronous processTurn
— grade + gated Gemini + TTS,
MP3 in the response body; SD-
cached prompts

Upload raw PCM to
processTurn (STT server-side);
keep-alive heartbeat

† Not instrumented (timers added at the MP3 baseline). * Still 5 hops, but warm — the up-
to-+12 s cold-start cliff is gone. Structural win: 5 → 2 → 1 network hops; inline-audio
decode dropped from a 2.6–3.8 s URL download to 2–4 ms.

Phase 2, measured live on hardware

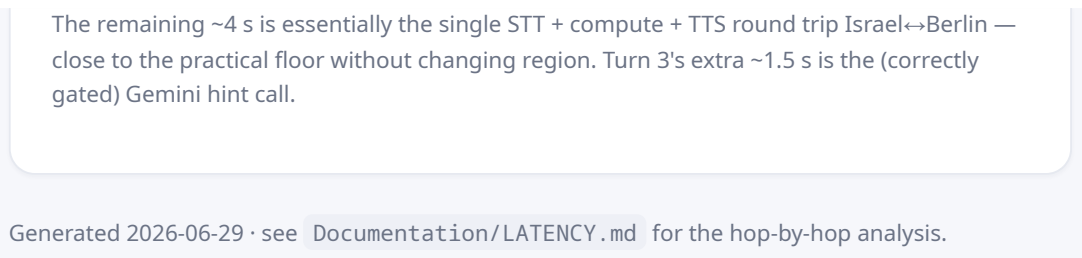
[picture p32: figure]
gated) Gemini hint call.

The remaining ~4 s is essentially the single STT + compute + TTS round trip Israel↔Berlin — close to the practical floor without changing region. Turn 3's extra ~1.5 s is the (correctly

Generated 2026-06-29 · see Documentation/LATENCY.md for the hop-by-hop analysis.

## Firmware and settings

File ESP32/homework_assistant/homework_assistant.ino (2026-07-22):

/**
 * Homework Assistant — ESP32-S3 firmware for the Pip tutor.
 * Board: LCDWIKI 2.8" ESP32-S3 Display (ES3C28P / ES3N28P).
 *
 * Runs the voice tutor loop end-to-end: identify the child by voice, speak each
 * question (Google TTS), record the answer over push-to-talk (I2S), send it to
 * the backend for grading, and show the returned emotion on the pip_face
 * display. Publishes deviceState so the parent app sees the device live.
 *
 * Libraries: ArduinoJson v7, TFT_eSPI (User_Setup per INTEGRATION.md).
 * Board settings: ESP32S3 Dev Module, 16MB flash, PSRAM "OPI PSRAM" (required),
 * Partition "Huge APP".
 */

#include <WiFi.h>
#include <time.h>
#include <driver/i2s.h>   // ESP32-S3 built-in I2S driver
#include "secrets.h"
#include "pins.h"
#include "es8311.h"
// pip_face animated face (TFT_eSPI). You MUST use the pre-patched TFT_eSPI from
// "ESP32/modified libraries/TFT_eSPI" (its User_Setup.h is already configured
// for this board), or TFT_eSPI will crash at init. See INTEGRATION.md.
#include "PipFace.h"
#include "firebase_client.h"
#include "stt_client.h"
#include "tts_player.h"
#include "tts_cache.h"     // SD-backed cache for static/repeated phrases (after the 3 above)
#include "esp_sleep.h"     // deep sleep + ext1 button wake (idle power policy)
#include "driver/rtc_io.h" // hold the button pins through deep sleep
#include "driver/gpio.h"   // hold the (non-RTC) backlight pin off through deep sleep

// ── Phase 1: collapse the turn into ONE synchronous processTurn call ──────────
// 1 = device calls processTurn (grade + Gemini + TTS + writes done server-side,
//     result returned inline; audio is the HTTP body). Removes the device's own
//     Firestore write, the Eventarc trigger, the poll loop, and the separate
//     audio download. 0 = legacy post+poll path (firestorePostLearningTurn +
//     firestorePollForTurnResult). Flip to 0 to A/B or fall back.
#ifndef USE_PROCESS_TURN
#define USE_PROCESS_TURN 1
#endif

// ── Phase 2: fold STT into processTurn (upload audio; server transcribes) ─────
// 1 = the device uploads the raw mono PCM straight to processTurn (?fmt=pcm16),
//     which runs STT itself, then grade + Gemini + TTS — ONE round trip for the
//     whole turn, with NO separate transcribeAudio handshake and a RAW-PCM upload
//     (no base64, −33% bytes over the slow uplink). Requires USE_PROCESS_TURN.
// 0 = transcribe on-device first (transcribeAudio), then send the TEXT to
//     processTurn (or to post+poll when USE_PROCESS_TURN=0). Flip to 0 to A/B or
//     fall back. The boot identify flow always uses on-device STT regardless.
#ifndef USE_PROCESS_TURN_AUDIO
#define USE_PROCESS_TURN_AUDIO 1
#endif

// ── Boredom nudge (PLAYFUL) ──────────────────────────────────────────────────
// While waiting for an answer with the screen still on, if this many SECONDS
// pass with no interaction, Pip shows a brief PLAYFUL wink to re-engage the
// child, then returns to the listening face. Fires at most once per idle
// stretch (reset on any interaction) and is purely visual — it never speaks or
// interrupts. Keep it well under SCREEN_OFF. 0 disables.
#ifndef BOREDOM_NUDGE_SECONDS
#define BOREDOM_NUDGE_SECONDS 40
#endif

// ── WiFi connect budget ───────────────────────────────────────────────────────
// Total time to keep trying WiFi at boot before giving up and powering down
// (deep sleep — a button press wakes it to try again). Prevents the device from
// sitting forever with a dead screen when the network is unavailable.
#ifndef WIFI_CONNECT_BUDGET_SECONDS
#define WIFI_CONNECT_BUDGET_SECONDS 300   // 5 minutes
#endif

// ── State machine ─────────────────────────────────────────────────────────────
enum State { IDLE, RECORDING, PROCESSING, SPEAKING };
State state = IDLE;
// After a recording ends while the button is STILL held (e.g. it hit the time
// limit), require a release before the next press can start a new recording —
// otherwise a long hold chains straight into back-to-back recordings.
bool g_requireBtnRelease = false;

// ── Audio record buffer (PSRAM) ───────────────────────────────────────────────
uint8_t* recordBuf  = nullptr;
size_t   recordBytes = 0;

// ── Tutor loop state ──────────────────────────────────────────────────────────
String g_currentQuestion = "";
// Subject of the active session. Seeded from SESSION_SUBJECT, but the
// kid's voice-pick during identify_subject overwrites the session doc in
// Firestore, and firestoreWaitForCurrentQuestion reads that value back
// into this global so STT/UI logic uses the actual chosen subject.
String g_currentSubject = SESSION_SUBJECT;
int    g_stars           = 0;     // running correct-answer count (shown on strip)
bool   g_haveFace        = false; // pip_face initialised OK

// ── Heartbeat ─────────────────────────────────────────────────────────────────
uint32_t g_lastHeartbeat = 0;
const uint32_t HEARTBEAT_MS = 10000;  // app online-timeout is 30s

// ── Idle power policy ─────────────────────────────────────────────────────────
// Timestamp of the child's last interaction (button press / finished answer).
// The loop turns the screen off after g_screenOffMinutes and deep-sleeps after
// g_deviceSleepMinutes of no interaction (both from the child's settings; see
// firebase_client.h). g_screenOff tracks whether the backlight is currently off.
uint32_t g_lastInteractionMs = 0;
bool     g_screenOff         = false;
// Boredom nudge (PLAYFUL): whether we've already winked for the current idle
// stretch, and when to revert the wink to the listening face.
bool     g_boredomNudged     = false;
uint32_t g_playfulUntilMs    = 0;
// Boot/wake counter — survives deep sleep (RTC memory). Reported in device
// telemetry so the app/report can show how many times the unit powered on.
RTC_DATA_ATTR uint32_t g_bootCount = 0;

// ─────────────────────────────────────────────────────────────────────────────
// Forward declarations — functions with DEFAULT ARGUMENTS
// ─────────────────────────────────────────────────────────────────────────────
// The Arduino builder auto-generates prototypes for functions defined in a .ino
// and inserts them at the top of the sketch, which is why most helpers can be
// called before they are defined. It deliberately SKIPS any function whose
// signature carries a default argument (emitting the default twice — once in the
// generated prototype, once in the definition — is illegal C++). Such functions
// therefore have to be declared by hand, or calls that appear earlier in the file
// fail with "was not declared in this scope".
//
// The default value must appear on the DECLARATION only; the definitions below
// repeat the parameter without "= ...".
void faceStatus(const char* status, int mood = -1);
bool recordOneAnswerBlocking(uint32_t maxWaitMs = 20000);

// ─────────────────────────────────────────────────────────────────────────────
// I2S setup for RECORDING (raw driver, full-duplex)
// ─────────────────────────────────────────────────────────────────────────────
void i2s_start_recording() {
  i2s_config_t cfg = {
    .mode             = (i2s_mode_t)(I2S_MODE_MASTER | I2S_MODE_TX | I2S_MODE_RX),
    .sample_rate      = SAMPLE_RATE,
    .bits_per_sample  = I2S_BITS_PER_SAMPLE_16BIT,
    .channel_format   = I2S_CHANNEL_FMT_RIGHT_LEFT,  // stereo — matches ES8311's 32-bit frame
    .communication_format = I2S_COMM_FORMAT_STAND_I2S,
    .intr_alloc_flags = ESP_INTR_FLAG_LEVEL1,
    .dma_buf_count    = 8,
    .dma_buf_len      = 512,
    .use_apll         = true,
    .tx_desc_auto_clear = true,
    .mclk_multiple    = I2S_MCLK_MULTIPLE_384,
  };
  i2s_pin_config_t pins = {
    .mck_io_num   = PIN_I2S_MCLK,
    .bck_io_num   = PIN_I2S_BCLK,
    .ws_io_num    = PIN_I2S_LRCK,
    .data_out_num = PIN_I2S_DOUT,
    .data_in_num  = PIN_I2S_DIN,
  };
  i2s_driver_install(I2S_PORT, &cfg, 0, NULL);
  i2s_set_pin(I2S_PORT, &pins);
  i2s_zero_dma_buffer(I2S_PORT);
}

void i2s_stop_recording() {
  i2s_driver_uninstall(I2S_PORT);
}

// ─────────────────────────────────────────────────────────────────────────────
// Helpers
// ─────────────────────────────────────────────────────────────────────────────
void connectWiFi() {
  Serial.printf("[WiFi] Connecting to %s", WIFI_SSID);
  WiFi.begin(WIFI_SSID, WIFI_PASSWORD);
  uint32_t attemptStart = millis();
  uint32_t bootStart    = millis();
  bool warned = false;
  while (WiFi.status() != WL_CONNECTED) {
    faceTick();                 // keep the face animating instead of a silent hang
    delay(250);
    Serial.print(".");
    // Total budget: don't retry forever. After WIFI_CONNECT_BUDGET_SECONDS with no
    // link, show OOPS and power down (deep sleep) — a button press wakes it to try
    // again — so the device never sits indefinitely with a dead screen.
    if (millis() - bootStart > (uint32_t)WIFI_CONNECT_BUDGET_SECONDS * 1000UL) {
      Serial.println("\n[WiFi] No connection within the boot budget — powering down.");
      faceStatus("error");
      faceStrip("אין חיבור לרשת. כבים — לחצו על הכפתור לנסות שוב.");
      faceTick();
      delay(3000);
      enterDeepSleep();         // does not return; wakes on the button
    }
    // Never hang silently: after ~20 s with no link, tell the user on screen and
    // kick a fresh association attempt, then keep trying (within the budget above).
    if (millis() - attemptStart > 20000) {
      if (!warned) {
        faceStatus("error");
        faceStrip("אין חיבור לרשת — מנסה שוב...");
        warned = true;
      }
      Serial.println("\n[WiFi] Not connected yet — retrying association...");
      WiFi.begin(WIFI_SSID, WIFI_PASSWORD);
      attemptStart = millis();
    }
  }
  Serial.println("\n[WiFi] Connected: " + WiFi.localIP().toString());
  if (warned) {
    // We showed the "no network" banner while down — now that we're back, clear the
    // stuck error face and confirm "מחובר!" for ~4 s, then wipe it so it doesn't linger.
    faceStatus("idle");
    faceStrip("מחובר!");
    uint32_t shownAt = millis();
    while (millis() - shownAt < 4000) { faceTick(); delay(50); }
    faceStrip("");   // clear the confirmation after 4 s
  }
  delay(500);
}

void syncClock() {
  // Real time is needed for Firestore timestamps + the app heartbeat freshness.
  configTime(0, 0, NTP_SERVER);     // UTC; gmtime_r() is used downstream
  Serial.print("[Time] Syncing NTP");
  time_t now = time(nullptr);
  uint32_t start = millis();
  while (now < 1000000000 && millis() - start < 10000) {
    delay(300);
    Serial.print(".");
    now = time(nullptr);
  }
  Serial.println(now < 1000000000 ? "  (failed — using placeholder time)"
                                  : "  ok: " + isoNow());
}

// Map the backend emotion vocabulary onto a pip_face emotion label.
const char* pipEmotionFor(const String& e) {
  if (e == "celebrating") return "celebrating";
  if (e == "proud")       return "proud";
  if (e == "happy")       return "happy";
  if (e == "encouraging") return "encouraging";
  if (e == "concerned")   return "concerned";
  if (e == "neutral")     return "happy";
  return "encouraging";
}

// These are no-ops when pip_face begin() failed, so the rest of the firmware
// never has to care whether the display actually came up.
void faceEmotion(const char* label) {
  if (g_haveFace) Pip::setEmotion(label);
}
void faceStatus(const char* status, int mood) {   // default (-1) is on the prototype above
  if (g_haveFace) Pip::setDeviceStatus(status, mood);
}
void faceStrip(const String& text) {
  if (g_haveFace) Pip::setStrip(text.c_str(), g_stars);
}
void faceTick() {
  if (g_haveFace) Pip::tick();
}

// Show the device's pairing code ON THE SCREEN (not just the Serial Monitor) so
// a parent can read it and link the device in the app. Shown whenever the device
// is unpaired — the code is stable (MAC-derived, devicePairingDocId in
// firebase_client.h), so it's the same value the parent types under "TUTOR-".
void showPairingCode() {
  const String code = devicePairingDocId();     // "TUTOR-XXXXXX"
  Serial.println("[Pairing] Show on screen — enter this code in the app: " + code);
  faceEmotion("sleepy");                         // calm "waiting to be set up" face
  faceStrip("להגדרה באפליקציה: " + code);
}

// Post-process the audio in recordBuf in-place: pick the channel that
// actually carries the mic, strip to mono, and reject near-silence.
// Returns true if the audio is usable for STT; false if too short / silent.
// recordBytes is updated to the mono-stripped length on success.
bool processRecordedAudio() {
  if (recordBytes < 1000) {
    Serial.println("[Audio] too short, ignoring.");
    return false;
  }
  // Pick the louder stereo channel (the codec is mono on one side).
  int micChannel = 0;
  {
    int16_t* raw = (int16_t*)recordBuf;
    size_t frames = recordBytes / 4;
    int64_t sumSq0 = 0, sumSq1 = 0;
    for (size_t i = 0; i < frames; i++) {
      sumSq0 += (int64_t)raw[i*2]   * raw[i*2];
      sumSq1 += (int64_t)raw[i*2+1] * raw[i*2+1];
    }
    float rms0 = sqrt((float)(sumSq0 / (int64_t)frames));
    float rms1 = sqrt((float)(sumSq1 / (int64_t)frames));
    micChannel = (rms1 > rms0) ? 1 : 0;
    Serial.printf("[Audio] ch0 RMS: %.0f  ch1 RMS: %.0f  -> ch%d\n", rms0, rms1, micChannel);
  }
  // Strip to mono.
  {
    int16_t* src = (int16_t*)recordBuf;
    int16_t* dst = (int16_t*)recordBuf;
    size_t frames = recordBytes / 4;
    for (size_t i = 0; i < frames; i++) dst[i] = src[i * 2 + micChannel];
    recordBytes = frames * 2;
  }
  // Boost quiet / far-field speech to a healthy STT level, then reject only true
  // silence (see micAutoGainMono). The low floor (130) accepts soft-spoken
  // children — the auto-gain lifts quiet-but-real speech above it.
  {
    float rms = micAutoGainMono();
    Serial.printf("[Audio] mono RMS: %.0f\n", rms);
    if (rms < 130) {
      Serial.println("[Audio] near-silence; speak closer.");
      return false;
    }
  }
  return true;
}

// ── Software mic auto-gain (far-field boost) ─────────────────────────────────
// The ES8311 analog PGA is already maxed (es8311.h reg14=0x1A), so a child who
// isn't right on top of the mic records quietly. This scales the captured mono
// utterance up toward a healthy full-scale peak, so quiet/distant
// speech reaches STT at a usable level. It's adaptive and peak-based: a loud close
// answer gets ~1x (never amplified into clipping), a quiet distant one up to
// MIC_MAX_GAIN. Operates in place on recordBuf (already stripped to mono); returns
// the PRE-gain RMS so the caller can still reject true silence.
#define MIC_TARGET_PEAK  22000   // ~-3.4 dBFS: loud, with headroom (full scale 32767)
#define MIC_MAX_GAIN     12.0f   // cap (~+21.6 dB) — raised 8→12 so quiet/far speech can reach
                                 // MIC_TARGET_PEAK instead of being capped short. Peak-targeted,
                                 // so close/loud speech still gets ~1x (no clipping).
static float micAutoGainMono() {
  int16_t* s = (int16_t*)recordBuf;
  size_t   n = recordBytes / 2;
  if (n == 0) return 0.0f;
  int32_t peak = 1; int64_t sumSq = 0;
  for (size_t i = 0; i < n; i++) {
    int32_t a = s[i] < 0 ? -s[i] : s[i];
    if (a > peak) peak = a;
    sumSq += (int64_t)s[i] * s[i];
  }
  float rms = sqrtf((float)(sumSq / (int64_t)n));   // pre-gain (for the silence reject)
  float g   = (float)MIC_TARGET_PEAK / (float)peak;
  if (g > MIC_MAX_GAIN) g = MIC_MAX_GAIN;
  if (g > 1.0f) {                                   // never attenuate a healthy signal
    for (size_t i = 0; i < n; i++) {
      int32_t v = (int32_t)lroundf(s[i] * g);
      if (v >  32767) v =  32767;                   // saturate (rare: g is derived from peak)
      if (v < -32768) v = -32768;
      s[i] = (int16_t)v;
    }
    Serial.printf("[Mic] auto-gain x%.1f (RMS %.0f -> %.0f)\n",
                  (double)g, (double)rms, (double)(rms * g));
  }
  return rms;
}

// Blocking record: face listens, waits for the push-to-talk button, captures the
// answer while it's held. Used by the boot-time identify flow before the main
// state-machine loop takes over.
bool recordOneAnswerBlocking(uint32_t maxWaitMs) {   // default (20000) is on the prototype above
  faceEmotion("listening");
  Serial.println("[Identify] Press the button and answer...");
  uint32_t waitStart = millis();
  while (digitalRead(PIN_BTN) != LOW) {
    faceTick();
    if (millis() - waitStart > maxWaitMs) {
      Serial.println("[Identify] No button press within timeout.");
      return false;
    }
    delay(20);
  }
  Serial.println("[Identify] Recording...");
  recordBytes = 0;
  i2s_start_recording();
  while (digitalRead(PIN_BTN) == LOW && recordBytes < RECORD_BUF_SIZE) {
    size_t bytesRead = 0;
    i2s_read(I2S_PORT,
             recordBuf + recordBytes,
             min((size_t)1024, RECORD_BUF_SIZE - recordBytes),
             &bytesRead, portMAX_DELAY);
    recordBytes += bytesRead;
  }
  i2s_stop_recording();
  Serial.printf("[Identify] Recorded %u bytes (%.1f s)\n",
                recordBytes, recordBytes / (float)(SAMPLE_RATE * 2));
  return true;
}

// Capture one spoken answer during the boot identify flow, RE-ASKING until the
// child actually says something the STT can transcribe. Never returns empty: it
// keeps re-prompting (with `retryPrompt`) and listening until it has a
// transcript, so the caller never has to fall back to a generic session just
// because the child was slow or silent.
String identifyCaptureAnswer(const char* retryPrompt) {
  while (true) {
    if (recordOneAnswerBlocking() && processRecordedAudio()) {
      faceEmotion("thinking");
      String t = transcribeAudio(recordBuf, recordBytes, g_idToken, "he-IL");
      if (!t.isEmpty()) return t;
    }
    // No trigger, silence, or unintelligible speech — re-ask and listen again.
    // retryPrompt is a fixed string → SD cache makes the re-ask instant.
    faceEmotion("encouraging");
    speakTextCached(retryPrompt);
  }
}
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
void loop() {
  faceTick();  // ~30fps internally; cheap to call every iteration
  checkIdlePolicy();  // screen-off / deep-sleep after inactivity

  // Heartbeat so the app keeps showing the device online. Uses the keep-alive
  // path (firestoreHeartbeat) so repeats cost ~0.1 s instead of a ~2 s handshake —
  // the device stays responsive to the button between heartbeats. Meaningful
  // state transitions still use firestoreWriteDeviceState().
  if (millis() - g_lastHeartbeat > HEARTBEAT_MS) {
    g_lastHeartbeat = millis();
    const char* hb = (state == IDLE) ? "listening" : "asking";
    firestoreHeartbeat(hb, g_currentQuestion);
  }

  // ── IDLE → button press ────────────────────────────────────────────────────
  // If the screen is currently OFF, the FIRST press only WAKES it (backlight on +
  // restart the idle timers) and is consumed here — the child must press AGAIN to
  // record. This stops a "tap to wake" from being swallowed as a (usually empty)
  // answer. If the screen is already on, the press starts recording as before.
  bool btnDown = (digitalRead(PIN_BTN) == LOW);
  if (!btnDown) g_requireBtnRelease = false;   // released → re-arm for the next press

  if (state == IDLE && btnDown && !g_requireBtnRelease) {
    if (g_screenOff) {
      Serial.println("[Main] Wake press — screen on; press again to answer.");
      noteInteraction();              // backlight on + reset the idle timers
      // Consume THIS press so the same hold doesn't roll straight into a recording.
      while (digitalRead(PIN_BTN) == LOW) { faceTick(); delay(10); }
    } else {
      Serial.println("[Main] Recording answer...");
      noteInteraction();              // reset the idle timers
      state = RECORDING;
      recordBytes = 0;
      faceEmotion("listening");
      i2s_start_recording();
    }
  }

  // RECORDING → capture while the button is held.
  if (state == RECORDING) {
    if (btnDown && recordBytes < RECORD_BUF_SIZE) {
      size_t bytesRead = 0;
      i2s_read(I2S_PORT,
               recordBuf + recordBytes,
               min((size_t)1024, RECORD_BUF_SIZE - recordBytes),
               &bytesRead, portMAX_DELAY);
      recordBytes += bytesRead;
      if (recordBytes >= RECORD_BUF_SIZE) {
        Serial.println("[Main] Buffer full — stopping recording.");
        btnDown = false;
      }
    }

    if (!btnDown) {  // button released (or hit the time limit) → process this answer
      i2s_stop_recording();
      // If we stopped on the time limit the button may still be held down; require
      // a release before the next recording so one long hold can't chain them.
      g_requireBtnRelease = true;
      state = PROCESSING;
      Serial.printf("[Main] Recorded %u bytes (%.1f sec)\n",
                    recordBytes, recordBytes / (float)(SAMPLE_RATE * 2));
      processCapturedAnswer();          // STT → grade → speak pipeline
    }
  }
}

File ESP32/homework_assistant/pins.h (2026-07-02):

#pragma once
// Board: LCDWIKI 2.8" ESP32-S3 Display (ES3C28P / ES3N28P)
// See ESP32/parameters.h for the full annotated pin table.

// ── Audio (ES8311 codec) ─────────────────────────────────────────────────────
#define PIN_AUDIO_EN    1    // LOW = speaker amp on
#define PIN_I2S_MCLK    4
#define PIN_I2S_BCLK    5
#define PIN_I2S_DOUT    8    // ESP32 → speaker  (confirmed from LCD Wiki echo example)
#define PIN_I2S_LRCK    7
#define PIN_I2S_DIN     6    // Microphone → ESP32 (confirmed from LCD Wiki echo example)

// ── ES8311 I2C ───────────────────────────────────────────────────────────────
#define PIN_I2C_SDA     16
#define PIN_I2C_SCL     15
#define ES8311_I2C_ADDR 0x18

// ── Button (push-to-talk, on IO2/IO3/IO14/IO21 expansion header) ─────────────
#define PIN_BTN         3    // IO3 — INPUT_PULLUP, active LOW
#define PIN_BTN_GND     2    // IO2 — set OUTPUT LOW to act as GND for the button
                             // Wire button between IO2 and IO3 on the expansion header.
                             // IO43/IO44 (UART) can't be used: TX idles HIGH, RX is
                             // held by UART peripheral.
//#define PIN_BTN       0    // (BOOT button fallback — GPIO0, if IO3 line is broken)

// ── RGB status LED (WS2812) ──────────────────────────────────────────────────
#define PIN_RGB_LED     42

// ── Display: ILI9341 SPI (driven by pip_face via TFT_eSPI) ───────────────────
// These do NOT collide with the I2S audio pins (4,5,6,7,8), the I2C codec/touch
// bus (15,16) or the button (2,3) — pip_face and the audio path coexist.
// TFT_eSPI itself is configured in its User_Setup (see pip_face/User_Setup_LCDWIKI.h).
// The backlight is NOT managed by TFT_eSPI/pip_face, so the firmware drives it.
#define PIN_LCD_BL      45   // Backlight enable (HIGH = on)
//      PIN_LCD_CS      10
//      PIN_LCD_MOSI    11
//      PIN_LCD_SCLK    12
//      PIN_LCD_MISO    13
//      PIN_LCD_DC      46
//      PIN_LCD_RST     -1   // tied to board reset; no dedicated GPIO

// ── I2S port ─────────────────────────────────────────────────────────────────
#define I2S_PORT        I2S_NUM_0

// ── Audio config ─────────────────────────────────────────────────────────────
#define SAMPLE_RATE     16000   // Hz — matches Google STT requirement
#define SAMPLE_BITS     16
#define MAX_RECORD_MS   7000    // max recording length in ms
#define RECORD_BUF_SIZE ((SAMPLE_RATE * SAMPLE_BITS/8 * 2 * MAX_RECORD_MS) / 1000)
// = 16000 * 2 * 2 (stereo) * 7 = 448000 bytes — fits in ESP32-S3's 8 MB PSRAM
// Stereo is required to match ES8311's 32-bit I2S frame (left=mic, right=zeros).
// Left channel is extracted after recording, halving the effective byte count.

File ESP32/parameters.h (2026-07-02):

// ─────────────────────────────────────────────────────────────────────────────
// Pin definitions for LCDWIKI 2.8" ESP32-S3 Display (ES3C28P / ES3N28P)
// https://www.lcdwiki.com/2.8inch_ESP32-S3_Display
// ─────────────────────────────────────────────────────────────────────────────
// NOTE: The old INMP441 / MAX98357A pin definitions are WRONG for this board.
// This board has an onboard ES8311 audio codec wired to the pins below.
// ─────────────────────────────────────────────────────────────────────────────

// ── Audio: ES8311 codec (I2S) ────────────────────────────────────────────────
#define AUDIO_ENABLE    1    // Low = speaker amp enabled (FM8002E enable pin)
#define I2S_MCLK        4    // Master clock (generated by ESP32-S3)
#define I2S_BCLK        5    // Bit clock
#define I2S_DOUT        8    // ESP32 → ES8311 → speaker (DAC output)
#define I2S_LRCK        7    // Left/Right clock (LRCK / WS)
#define I2S_DIN         6    // ES8311 → ESP32 (ADC input from mic)

// ── ES8311 codec config (I2C, shared with touch screen) ─────────────────────
#define CODEC_I2C_SDA   16   // Shared with FT6336G touch IC
#define CODEC_I2C_SCL   15   // Shared with FT6336G touch IC
#define ES8311_ADDR     0x18 // ES8311 I2C address (ADDR pin pulled low)

// ── Display: ILI9341 (SPI) ───────────────────────────────────────────────────
#define LCD_CS          10
#define LCD_DC          46
#define LCD_CLK         12
#define LCD_MOSI        11
#define LCD_MISO        13
#define LCD_BL          45   // Backlight (HIGH = on)

// ── Touch screen: FT6336G (I2C, same bus as codec) ──────────────────────────
#define TOUCH_SDA       16   // Same as CODEC_I2C_SDA
#define TOUCH_SCL       15   // Same as CODEC_I2C_SCL
#define TOUCH_RST       18
#define TOUCH_INT       17

// ── RGB LED (WS2812 single-wire) ─────────────────────────────────────────────
#define RGB_LED         42

// ── Push-to-talk button (on IO2/IO3/IO14/IO21 expansion header) ──────────────
#define BTN_RECORD      3    // IO3 — INPUT_PULLUP, reads button state (active LOW)
#define BTN_GND         2    // IO2 — OUTPUT LOW, acts as GND for the button
                             // Wire the button between IO2 and IO3.
                             // IO43 (UART RX) and IO44 (UART TX) are unusable:
                             // UART TX idles HIGH; UART peripheral holds RX.

// ── SD card (SDIO) ───────────────────────────────────────────────────────────
#define SD_CLK          38
#define SD_CMD          40
#define SD_DATA0        39
#define SD_DATA1        41
#define SD_DATA2        48
#define SD_DATA3        47

// ── Battery ADC ─────────────────────────────────────────────────────────────
#define BATTERY_ADC     9

// ── UART (debug / external serial) ─────────────────────────────────────────
#define UART_RX         43
#define UART_TX         44

// ── Free expand pins ────────────────────────────────────────────────────────
// IO2  → available
// IO3  → available
// IO14 → available
// IO21 → available

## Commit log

2026-07-03 add google sign-in option and connect device later; remove commited node_modules
2026-07-04 Switch to PTT button, add session-end-reason tracking, block sessions on unpaired devices, network-error/pairing voice prompts
    [homework_assistant.ino]
2026-07-05 Add per-child break policy, device-connect help, and cleanups
    - Break policy: breakFirstQuestions/breakEveryQuestions/breakAfterMinutes in ChildSettings, a settings section, and tutorEngine.js reading them + a session-time trigger (was hardcoded 'תוקספה' 7/4).
    - Device page: remove unused remote-control; pairing sheet now shows connection steps. Remove the in-app mock simulation.
    - Onboarding: device-connect slide, white skip button, skip-hint note.
    - Firestore: add materials + sessions composite indexes (fixes 'query requires an index'); remove duplicate index file.
    - AuthGate rebuilds only on hasSeenIntro (fixes shell resetting to the home tab).
2026-07-05 Add idle power policy: screen-off + deep-sleep, per-child configurable
    After a child's configurable inactivity thresholds the device turns its screen off (default 15 min) then enters deep sleep (default 50 min, wakes on the push-to-talk button), replacing the fixed 5-min cloud inactivity cut.
    - app: screenOffMinutes/deviceSleepMinutes in ChildSettings + two Settings sliders (יטמוטוא יוביכ)
    - functions: monitorTutor ends a lesson by inactivity at the child's deviceSleepMinutes instead of a hardcoded 5 min
    - firmware: read both thresholds from the child doc at boot; backlight off + esp_deep_sleep (ext1 button wake) via local idle timers
    [homework_assistant.ino]
2026-07-05 Validate uploaded materials: age/subject check, require a question, block bad ones from practice
    The extraction call now also returns an appropriateness verdict (age + subject) in the same Gemini request — no extra round-trip. Material judged unsuitable is force-disabled with a reason and stored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
    The app surfaces these: a warning on the list tile and a banner in the material detail, and it locks the enable toggle for content-blocked materials so a parent can't include them in the child's prac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
2026-07-05 Harden wake-word runtime: warm-up fix, adaptive noise gate, margin rule, refractory, false-fire quench
    Fixes a real bug (first ~1s of polls after every re-arm scored a zero-padded window — out-of-distribution input that could false-fire) and adds model-agnostic gates: rolling ambient-RMS gate (slow rise/fast fall, capped) that keeps steady fan/AC/TV noise from ever reaching the CNN, a class-margin rule that makes lowering the threshold per-home safe, a 2.5s refractory after a fire, and a caller-side quench (2 no-speech triggers in 60s -> +0.05 threshold for 30s, silent re-arm). Zero added latency, ~28B RAM, net CPU saving.
    WAKE_WORD.md: updated pipeline description, full knob table (was s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
    [homework_assistant.ino]
2026-07-05 Add wake-word retraining kit: real-data pipeline scripts + Hebrew capture checklist
    Materializes RETRAIN_RUNBOOK.md's reference snippets into smoke-tested scripts: build_dataset.py (one command: real SD recordings + edge-TTS voices incl. Hebrew + synthetic noise -> X_c*.npy shards for the existing train.py), real_data.py (loads /ww captures, ambient sliced first so real room noise feeds every mix; stdlib-wave fallback), augment.py, tts_edge.py. CAPTURE_CHECKLIST.md walks the ~15min recording session + train/export/parity/deploy steps.
2026-07-06 Fix device-connection reactivity: DeviceProvider follows child.deviceId
    After signup+pairing or a device swap, the 'connected' status only updated after a logout+login. DeviceProvider watches deviceState/{id} but nothing re-pointed it at the new deviceId on pairing — only an indirect postFrame hook in app.dart did, unreliably.
    Fix: DeviceProvider.syncTo() follows the active child's linked device; main.dart wires childProvider.addListener -> deviceProvider.syncTo(child.deviceId), so pairing/swap/child-switch update 'connected' immediately. Removed the fragile postFrame hook from app.dart.
2026-07-06 Enforce one-device-to-one-child: clear stale deviceId links on pairing
    A physical device has a stable UID + MAC-derived pairing code and resolves its child via 'children where deviceId==UID limit 1'. Pairing the same device to a new child never cleared the old child's deviceId, so two children shared it and the device's limit-1 query stuck to the stale (old) child ('always loads Naama').
    New Cloud Function enforceDeviceUniqueness (onWrite children/{id}) clears the deviceId from every other child when one is paired to a new device — newest pairing wins, across accounts. The device picks up the correct child on its next resolve (session-end restart).
2026-07-06 Process uploaded material questions: natural phrasing + smart grading
    Uploaded-material questions were stored/spoken raw (e.g. '7+2'), unlike generated ones .so TTS read them mechanically ,)'?2 דועו 7 הז המכ'(Extraction now instructs Gemini to phrase each question as a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
2026-07-06 Show device pairing code on screen, not just Serial Monitor
    An unpaired device published its TUTOR-XXXXXX pairing code only to Firestore + Serial and showed 'error' on screen, so a parent couldn't pair without a serial monitor. New showPairingCode() puts the code on the pip_face strip (bidiToVisual handles the Hebrew+code mix) whenever the device detects it's unpaired (needsPairing), and it stays visible across the 15s retry loop.
    [homework_assistant.ino]
2026-07-06 Fix English material questions + harden extraction parsing
    - English uploads now yield Hebrew-framed translation questions (no picture refs, no letter-spelling)
    - Salvage complete Q&A pairs from truncated Gemini responses instead of dropping all
    - Bump maxOutputTokens 2000 to 4000 to avoid truncation on larger worksheets
2026-07-06 Power down at session end instead of rebooting
    - Session end now enters deep sleep (a button press wakes a fresh session) instead of ESP.restart(), so the device goes dark and quiet rather than springing back on fully powered
    - Hold the backlight pin (IO45, non-RTC) off through deep sleep so the screen stays fully dark, not floating
    [homework_assistant.ino]
2026-07-06 Fix idle power policy and power down at session end
    - Idle screen-off / deep-sleep never elapsed in wake-word mode: a false wake-word fire (room noise, no speech) reset the idle timer. Only confirmed speech counts as interaction now, so the 15/50-min timers actually fire.
    - Session end now enters deep sleep (a button press wakes a fresh session) instead of ESP.restart(), so the device powers down instead of rebooting fully on.
    - Hold the backlight pin (IO45, non-RTC) off through deep sleep so the screen stays fully dark.
    [homework_assistant.ino]
2026-07-06 Wrap the question strip to 2 lines instead of clipping
    - Long questions overflowed the 240px strip and were cut off on one line; word-wrap to up to 2 right-aligned lines now.
    - Bump the strip text buffer 64 to 128 bytes so long questions aren't truncated before render.
2026-07-06 Recognize Hebrew in English lessons via STT alternative language
    English lessons ask the question in Hebrew, so children often answer in Hebrew (עדוי אל ,בלכ). en-US STT alone mis-heard בלכ as 'Caleb'; add he-IL as an alternativeLanguageCode so Google auto-detects both. Math stays Hebrew-only to avoid mis-reading spoken Hebrew numbers.
2026-07-10 Show pairing code on screen at boot for unpaired devices
    The code only appeared after the spoken identify flow returned needsPairing, which needs a button press + name a new device can't give. Gate on g_childId (resolved by deviceId at boot): if unpaired, show the code and wait for the parent to link a child.
    [homework_assistant.ino]
2026-07-10 fixed turn off problema
    [homework_assistant.ino]
2026-07-10 added mock for new device
2026-07-11 Fix grading false positives, renamed-child identify loop, WiFi boot hang; ignore memory/
    [homework_assistant.ino]
2026-07-17 Prepare repo for course submission: README, Parameters, Assets, secrets template, usage docs, cleanup
    [pip_main_body.stl, pip_rear_cover.stl]
2026-07-17 Wire PROUD (streak) and PLAYFUL (boredom nudge) faces; docs + params
2026-07-17 Add device-side telemetry (RSSI, heap, uptime, boot count, TTS cache) to deviceState
2026-07-18 added button to hardware schematics
2026-07-18 fixed what was broken
    [homework_assistant.ino]
2026-07-18 Fix network-error reprompt to show OOPS face; clarify FACE_STATE_MACHINE tables
    [homework_assistant.ino]
2026-07-18 Stale-answer guard (turnSeq resync); clear WiFi error banner on reconnect
    [homework_assistant.ino]
2026-07-18 Require button release after a recording (prevents chained recordings on a long hold)
    [homework_assistant.ino]
2026-07-18 Firmware: power down after 5 min of no WiFi at boot; require button release after each recording
2026-07-18 Reword device-offline alert to 'no recent activity' (remove 'heartbeat')
2026-07-18 WiFi reconnect: show 'רבוחמ!' for 4s then clear it
2026-07-18 Print exchangeId to Serial on each processTurn
2026-07-19 removed excess button images
2026-07-19 Material: switch to generated questions once every uploaded question has been asked (no recycle)
2026-07-20 Rebrand app UI 'Emotional Tutor' → 'Pip - Personal Tutor for Kids'
2026-07-20 Gender-aware Hebrew addressing
    - SYSTEM_PROMPT instructs Gemini to match child gender in all addressing
    - Fix deterministic feedback bug: 'ידובכה לכ' → gendered הפולא/ףולא
    - Reword backend + firmware identify prompts per review
    [homework_assistant.ino]
2026-07-20 Fix pairing: refresh deviceState heartbeat while unpaired
    The unpaired pairing-wait loop polled for a linked child every ~8s but never wrote deviceState, so ~60s after boot the app's freshness check (pairingMaxHeartbeatAgeSec=60) saw a stale heartbeat and refused pairing with 'device found but no recent report'. Write a heartbeat on each poll so the device stays pairable the whole time it's powered on.
    [homework_assistant.ino]
2026-07-20 createSession: retry with backoff instead of halting on transient failure
    [homework_assistant.ino]
2026-07-20 Siblings can share one device: per-parent uniqueness + add-child UI
2026-07-20 Firmware: log child level + re-resolve identified child's profile after identify
    [homework_assistant.ino]
2026-07-20 Report active child in deviceState + show it on the device monitor
2026-07-20 Technician reset also unpairs the device (back to pairing)
2026-07-20 Reword identify prompts: 'ךלש םשה תא' → 'ךמש תא'
2026-07-20 Identify prompts consistent-masc + clear 'רבוחמ!' after pairing
2026-07-20 Dashboard: show child name instead of device serial
2026-07-20 Per-child device separation (gate live status by activeChildId) + sibling-device button
2026-07-20 Per-child separation fixes: legacy fallback, attribute only after identify, idle gate
    [homework_assistant.ino]
2026-07-20 Family device: pairing via any child propagates to all siblings; new child inherits
2026-07-20 Continue prompt: three-way yes/no/re-ask; recognize 'םייסנ אוב' as exit
2026-07-20 Continue-flow fix, dismissible alerts, faster STT model + latency breakdown logs
2026-07-20 Continue-flow + gendered prompts + dismissible alerts + faster STT/Gemini + latency logs
2026-07-21 Identify: 'ךלש םשה' → 'ךמש' in prompts
2026-07-21 Firmware: drop ambiguous 'ךתוא' from reprompt (TTS gender misread)
2026-07-21 Identify: 'ךל םיארוק ךיא' phrasing; drop ambiguous 'ךתוא'
2026-07-21 App: clear-all button in alerts sheet
2026-07-21 Fill-in-blank fixes: bidi keeps English phrase order; TTS skips underscores
    [PipFace.cpp]
2026-07-21 Feedback: rotate praise word (was always הפולא/ףולא)
2026-07-22 Session cap: ignore unsynced device clock (session ended after Q1 on NTP-blocked network)
